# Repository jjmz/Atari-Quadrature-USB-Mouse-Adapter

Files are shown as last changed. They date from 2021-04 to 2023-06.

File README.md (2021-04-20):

# Atari-Quadrature-USB-Mouse-Adapter

New branch : uses platformio instead of ch554_sdcc. (Some init code from ch554_sdcc)

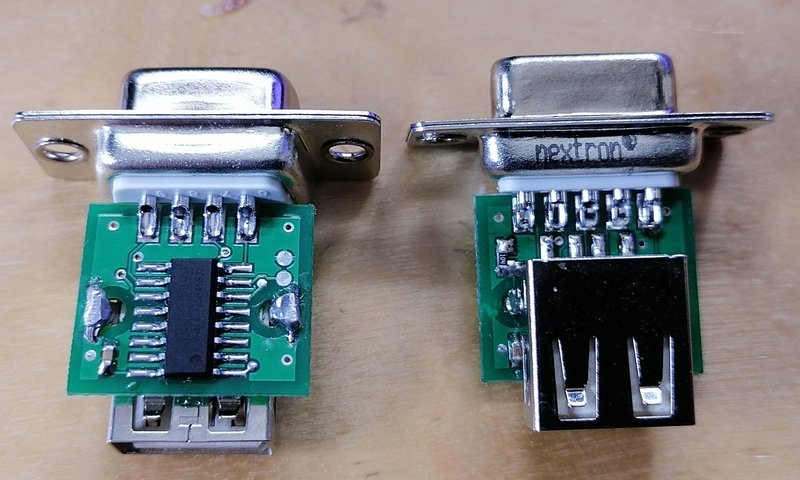
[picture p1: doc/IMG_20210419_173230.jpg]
Proto Photo


More info here : https://blog.pommerie-michel.fr/from-prototype-to-final-version-smallymouse-like-adapter-with-ch554/

Useful Tools :

- https://eleccelerator.com/usbdescreqparser/
- PyWinUsb - (examples/raw_data.py to check raw HID joystick output)
- SmallyMouse2 code source, for inspiration
-

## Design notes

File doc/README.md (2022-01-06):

# Doc

[Photo Gallery](https://github.com/jjmz/Atari-Quadrature-USB-Mouse-Adapter/blob/v2-platformio/doc/gallery.md)

[Reflash adapter - Linux](https://github.com/jjmz/Atari-Quadrature-USB-Mouse-Adapter/blob/v2-platformio/doc/ISP-Prog2.md)

[Reflash adapter - Windows](https://github.com/jjmz/Atari-Quadrature-USB-Mouse-Adapter/blob/v2-platformio/doc/ISP-Prog.md)

** Status LED

- LED OFF :
	Problem : CH554 not programmed, or in boot mode ?
	
	Boot mode is entered if the ISP pins are shorted
	
	It can be either P3.6 to VCC , or P1.5 to GND
	
	Note that P3.6 to VCC can happen if a full-speed device is connected to USB, thus the default on this project should really be P1.5. Please check that you are using this setting in the Windows WCH Flashing tool.

- LED ON, still :
	Program running, no recognized device on USB

- LED Blinking regularly :
	Mouse detected - mouse mode

- LED Pulsing : 1 pulse
	Joystick detected - default config (i.e. no specific config found)

- LED Pulsing : 2 pulses
	Joystick detected - using an entry in the joystick table

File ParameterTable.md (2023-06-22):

**WAS** DataFlash Offset:
**NOW** Memory Base : 0x3700 (i.e. 256 bytes before end of file)

    #0 (x02) - mouse DPI divider / TODO : bit 7 for Atari/Amiga switch
    #1 (x03) - step multiplier
    #2 (x08) - minimal increment
    #3 (x20) - maximal increment
    #4 -> #15 - to be used for buttons

    #16 - start of joystick table
        - one joystick entry => 20 bytes

Joystick Table

    #0-1 (0x0000) - Vendor ID (0 for default entry ,i.e. first one , 0xFFFF for unused)
    #2-3 (0x0000) - Product ID (0 for default entry, i.e first one)

    #4-5   (0x11-0x40) condition/value for Up
    #6-7   (0x21-0xC0) condition/value for Down
    #8-9   (0x10-0x40) condition/value for Left
    #10-11 (0x20-0xC0) condition/value for Right
    #12-13 (0x33-0xFF) condition/value for Fire Button 1 (multiple joystick buttons can trigger Fire)
    #14-15 (0xFF-0xFF) condition/value for Fire Button 2 (multiple joystick buttons can trigger Fire)
    #16-17 (0xFF-0xFF) condition/value for Fire Button 3 (multiple joystick buttons can trigger Fire)
    #18-19 (0xFF-0xFF) not used

Conditions encoding :

    0x0A-0xBB -> value at index A equals to BB
    0x1A-0xBB -> value at index A Lower than BB
    0x2A-0xBB -> value at index A Greater than BB
    0x3A-0xBB -> (value at index A and BB(mask)) is not zero
    0x4A-0xBB -> same as 0x1A (<) , but signed compare (ie 0x80 < 0x00 < 0x7F)
    0x5A-0xBB -> same as 0x2A (>) , but signed compare (ie 0x7F > 0x00 > 0x80)

Some examples :

- DragonRise - 0x0079 / 0x0006 - X,Y @ 0x01/0x00, buttons @ 0x06

    0x0F, 0x00,0x79,0x00,0x06, 0x11,0x40,0x21,0xC0, 0x10,0x40,0x20,0xC0, 0x36,0xFF,	

- 8bitdo / SN30 Pro - 0x2DC8 / 0x6001 - X,Y @ 0x04/0x03, buttons @ 0x00

    0x0F, 0x2D,0xC8,0x60,0x01, 0x14,0x40,0x24,0xC0, 0x13,0x40,0x23,0xC0, 0x30,0xFF,

- Logitech ATK3 - ???? ???? - X,Y @ 0x01/0x00, buttons @ 0x03

    cf Default Config

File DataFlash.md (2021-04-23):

DataFlash Offset:

    #0 (x02) - mouse DPI divider / TODO : bit 7 for Atari/Amiga switch
    #1 (x03) - step multiplier
    #2 (x08) - minimal increment
    #3 (x20) - maximal increment

    #4 - start of joystick table

Joystick Table

    #0 (0x0F) - offset to next table entry / 0xFF for last

    #1-2 (0x0000) - Vendor ID (0 for default entry)
    #3-4 (0x0000) - Product ID (0 for default entry)

    #5-6 (0x11-0x40) condition/value for Up
    #7-8 (0x21-0xC0) condition/value for Down
    #9-A (0x10-0x40) condition/value for Left
    #B-C (0x20-0xC0) condition/value for Right
    #D-E (0x33-0xFF) condition/value for Fire Button 1 (multiple joystick buttons will trigger Fire)

Conditions encoding :

    0x0A-0xBB -> value at index A equals to BB
    0x1A-0xBB -> value at index A Lower than BB
    0x2A-0xBB -> value at index A Greater than BB
    0x3A-0xBB -> (value at index A and BB(mask)) is not zero
    0x4A-0xBB -> same as 0x1A (<) , but signed compare (ie 0x80 < 0x00 < 0x7F)
    0x5A-0xBB -> same as 0x2A (>) , but signed compare (ie 0x7F > 0x00 > 0x80)

Some examples :

- DragonRise - 0x0076 / 0x0006 - X,Y @ 0x01/0x00, buttons @ 0x06

    0x0F, 0x00,0x79,0x00,0x06, 0x11,0x40,0x21,0xC0, 0x10,0x40,0x20,0xC0, 0x36,0xFF,	

- 8bitdo / SN30 Pro - 0x2DC8 / 0x6001 - X,Y @ 0x04/0x03, buttons @ 0x00

    0x0F, 0x2D,0xC8,0x60,0x01, 0x14,0x40,0x24,0xC0, 0x13,0x40,0x23,0xC0, 0x30,0xFF,

- Logitech ATK3 - ???? ???? - X,Y @ 0x01/0x00, buttons @ 0x03

    cf Default Config

DataFlash can be programmed independantly from the firmware code using the WCHISPTOOL.EXE
(Have not found a Linux program to modify DataFlash area)

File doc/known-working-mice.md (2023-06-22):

# Mice support

Tested (personally) :

| Name | USB IDs | Name (Linux) |
| --- | --- | --- |
| Cherry MC1000 | 046a:b091 | Cherry GmbH |
| Dell (M-UR69 ?) | 046d:c00c | Logitech, Inc. Optical Wheel Mouse |
| Dell (MS111-L ?) | 046d:c05a  | Logitech, Inc. M90/M100 Optical Mouse |
| Logitech B100 | 046d:c077 | Logitech, Inc,. M105 Optical Mouse |
| Logitech M185 | 046d:c542 | Logitech, Inc. Wireless Receiver |
| Dell (M-UAR DEL7 ?) | 413c:3012 | Dell Computer Corp. Optical Wheel Mouse |
| HAMA AMW-300 | xxxx:xxxx | HAMA wireless ("Action") |
| ACER AMR 9200 | 3938:1197 | Wireless (From Combo pack) |

Reported OK too by users :

| Name | USB IDs | Name (Linux) | Reporter |
| --- | --- | --- | --- |
| Microsoft sidewinder laser | | | |
| Logitech M720 (Dongle / BT mouse) | | | |
| Wireless (dongle) Logitech T620 touch mouse | | | |
| Logitech RX300 | | | |
| Genius GM-050014 U/A  Traveller 100 | | | |
| Seitek Cable Mouse, Model: PM34Azb | | | AndYManOne |
| Amazon, Model: Smartfox (Wireless) | | | AndYManOne |
| NoName Mouse, Model 1886 (Wireless) | | | AndYManOne |
| Red4Power, Model: R4-M010B (Wireless) | | | AndYManOne |
| Perrixx Mouse, Model: Perimice-711 (Wireless) | | | AndYManOne |
| Logitech Mouse, Model: M705 (Wireless) | | | AndYManOne |
| Logitech Zone Touch Mouse, Model T400 (Wireless) | | | AndYManOne |
| NN Mouse (No Model) The very flat version (Wireless) | | | AndYManOne |
| Sunflower Cable Mini Optical Mouse, Model: SF-2035 | | | AndYManOne |
| Logitech Cable Mouse, Model: RX 250 | | | AndYManOne |
| A500 Mini - original USB Amiga-Style Cable Mouse | | | AndYManOne |

Not Working

| Name | Remark |
| --- | --- |
| HAMA AMW-150 (wireless) | Not supported in Dell BIOS |
| Speedlink, Model: AXON SL6302-GY (Wireless) | |
| Microsoft Mouse, Model: 1850 (Wireless)  | |

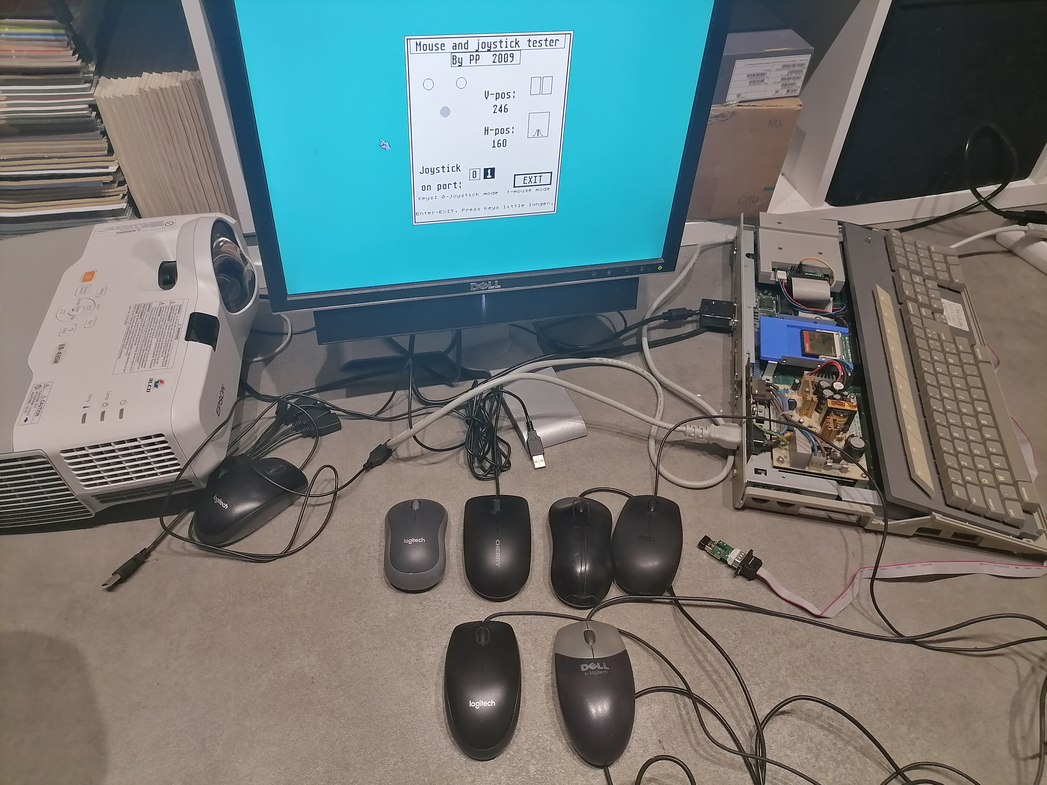
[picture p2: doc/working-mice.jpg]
working-mice


# Joysticks

From the joystick table (.h file)

| "Name" | USB IDS | Pic1 | Pic2 |
| --- | --- | --- | --- |
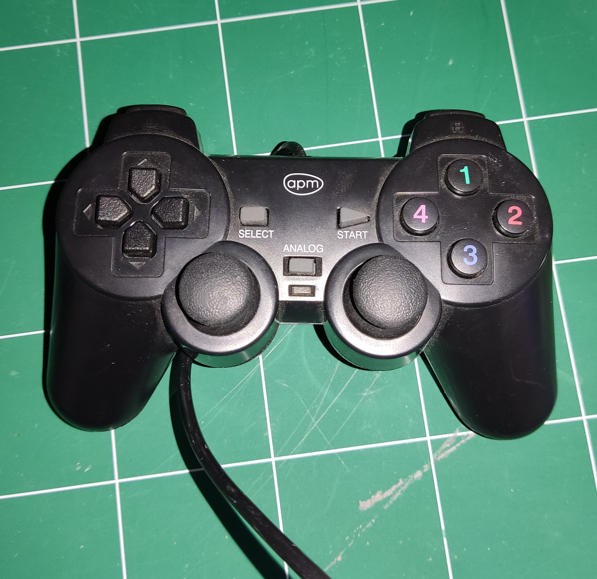
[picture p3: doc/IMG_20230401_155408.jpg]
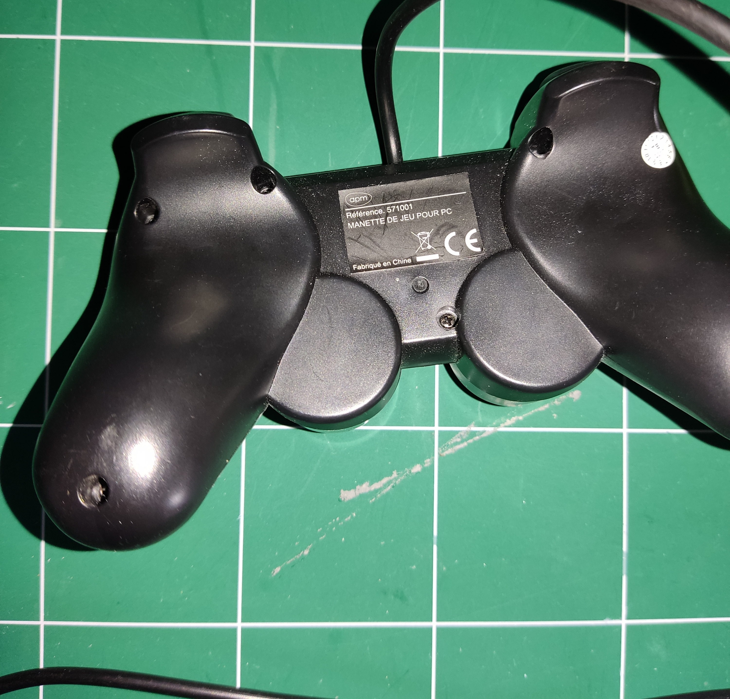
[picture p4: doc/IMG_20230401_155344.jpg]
| TWINSHOCK (Also DragonRise Inc. Generic USB Joystick) |	0079-0006 |  |  |
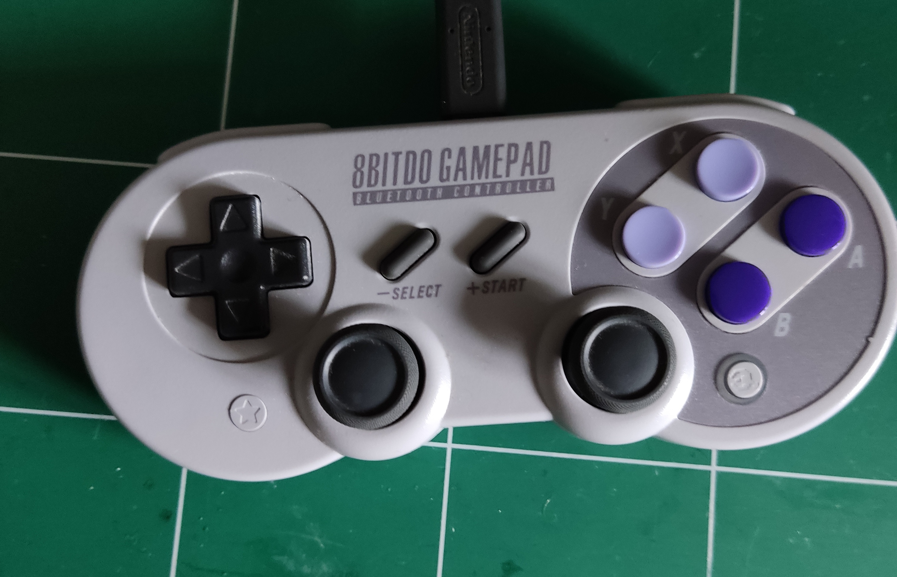
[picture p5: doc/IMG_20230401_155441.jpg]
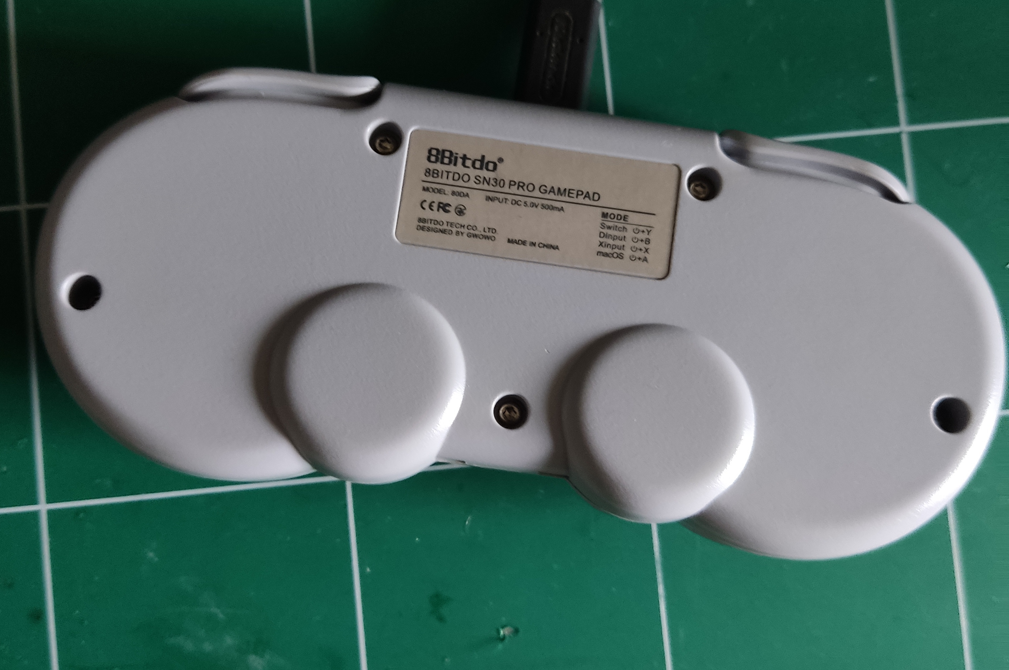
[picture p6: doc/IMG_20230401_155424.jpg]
| EIGHTBITDO_SN30 (Dinput mode) | 2DC8-6001	|  |  |
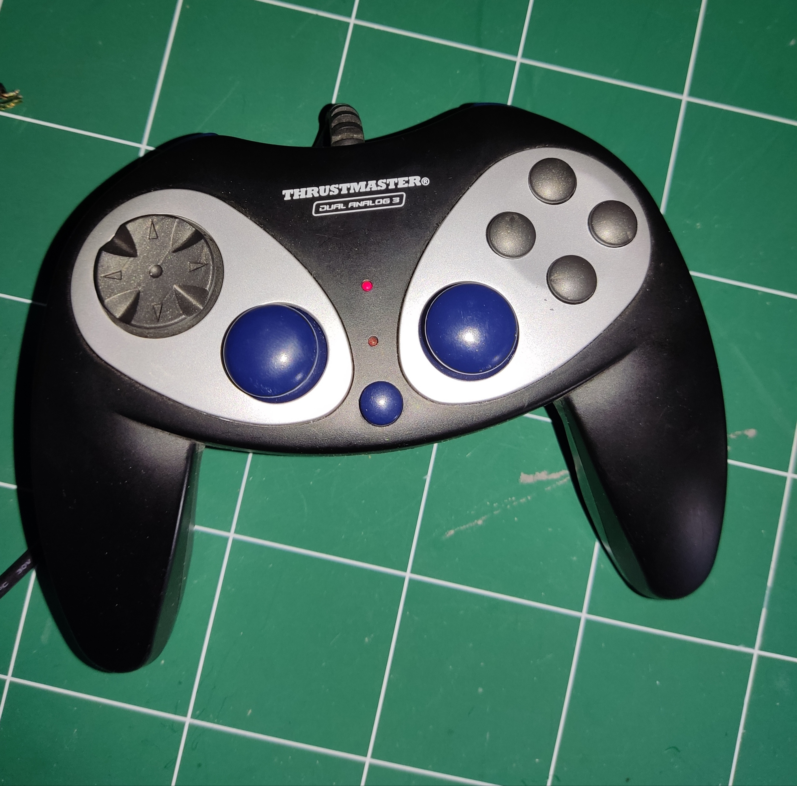
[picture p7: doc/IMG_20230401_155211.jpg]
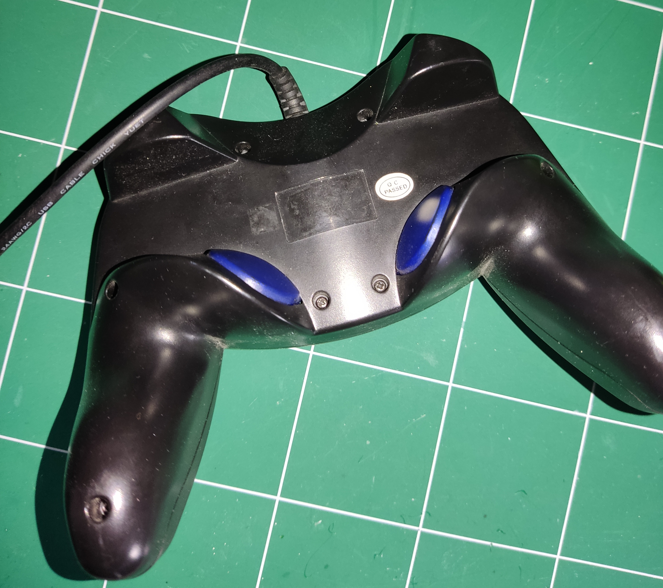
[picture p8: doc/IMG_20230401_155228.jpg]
| THRUSTMASTER | 044F-B315 |  |  |
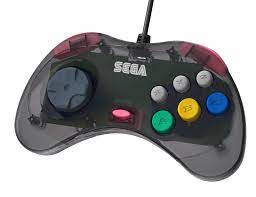
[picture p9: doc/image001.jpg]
| PAD | 0079-0011 |  | |
| GP1 | 0810-E501 | | |
| GP3 | 0810-0003 | | |
| HAMA | 12BD-A02F | | |
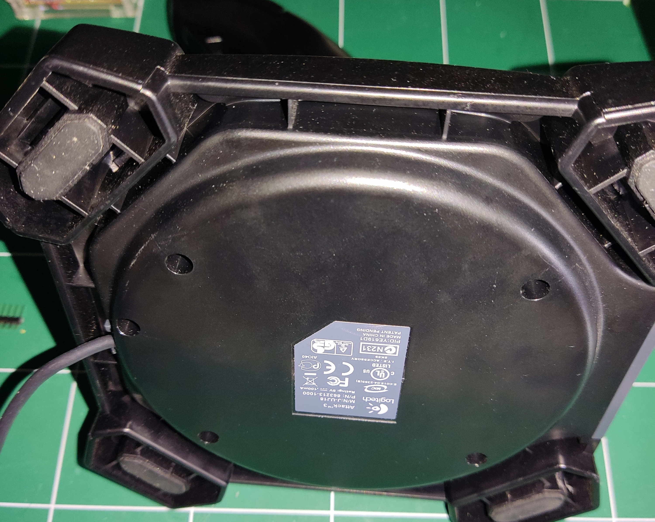
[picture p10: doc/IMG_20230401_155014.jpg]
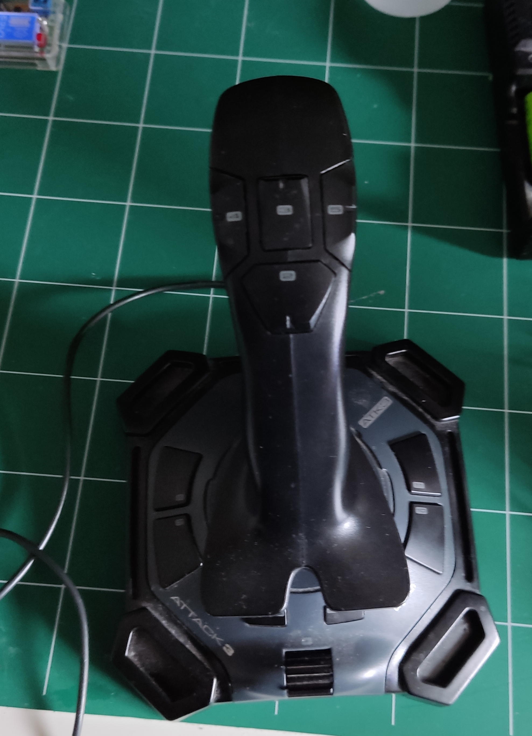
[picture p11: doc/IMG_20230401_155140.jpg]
| LOGITECH_ATK3 | 046D-C214 |  |  |
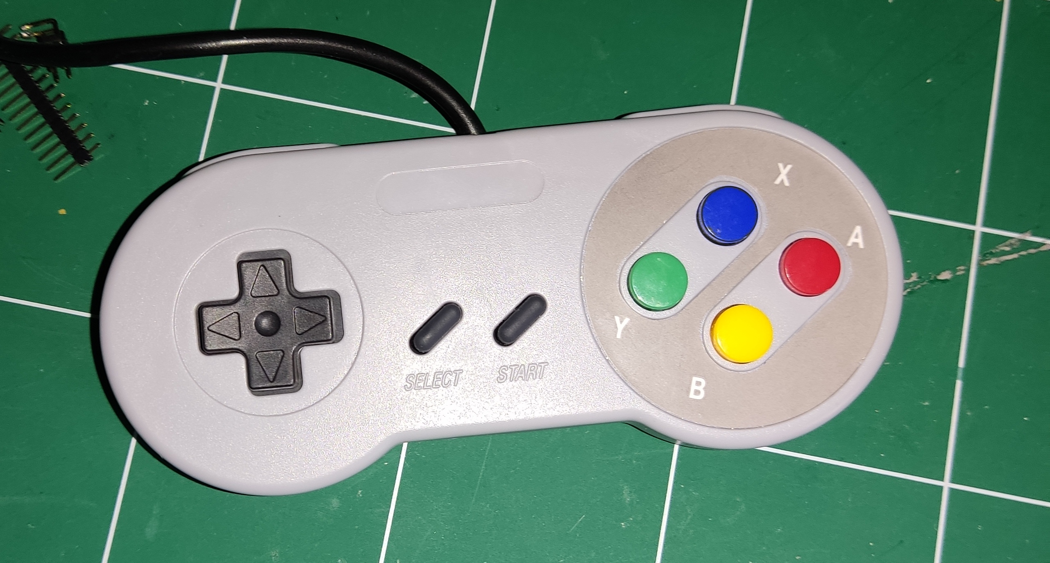
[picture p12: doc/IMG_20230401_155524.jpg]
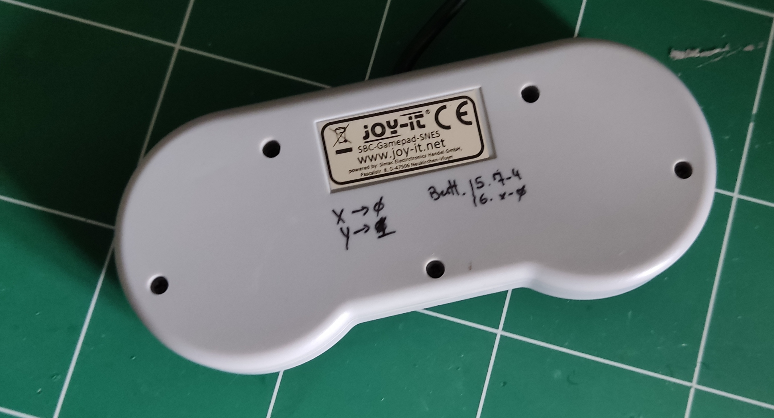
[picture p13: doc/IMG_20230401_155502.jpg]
| By Default (for example USBID) | xxxx-xxxx (081f-e401) |  |  |

Best Value : https://www.gotronic.fr/art-manette-pour-superpi-usb-gamepad-29672.htm

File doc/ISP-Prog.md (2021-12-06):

## CH55x Bootloader

I think you can have 3 cases when powering the CH55x :

1. Unprogrammed CH55x

   When the CH55x is unprogrammed, it will by default go in bootloader mode, with no specific pin to short.

2. Factory default (after 1st flashing, if nothing is done regarding download cfg), or if P3.6 was selected

   To go in bootloader mode, then a __temporary__ connection of P3.6 with VCC is needed while powering the chip.
   This __SHOULD NOT__ be the default for this project, as connecting a full-speed device to the USB would cause the CH55x to enter bootloader mode too (Full-speed devices have a pull-up connected to D+).
   On the USB adapter, VCC and P3.6 are accessible on two test pads, near the USB connector (check the photos with the tweezers)

3. Alternative download cfg : via P1.5 - info found here[^1]

   This is the configuration I am using - note that P1.5 has to be connected to GND - both pins are present on the DB-9 connector : P1.5 is pin 2 , GND is pin 8.
   You can use a short wire, or even a paper clip to connect those 2 pins, and can even leave it after powering the adapter, while reflashing.

## Windows WCH utility

Software to use : WCHISPTOOL ([local copy here](WCHISPTool_Setup.exe?fileId=854562))

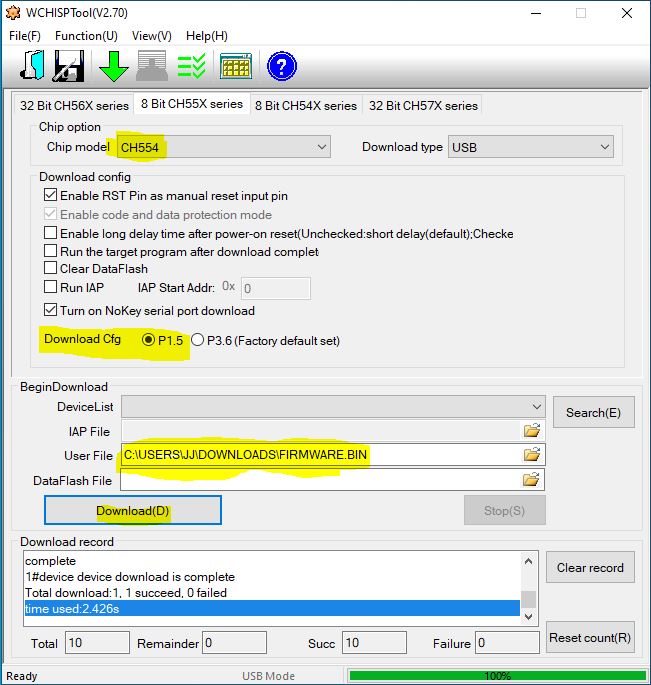
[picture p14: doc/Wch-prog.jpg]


Need to use a Male-Male USB cable (or adapter) :

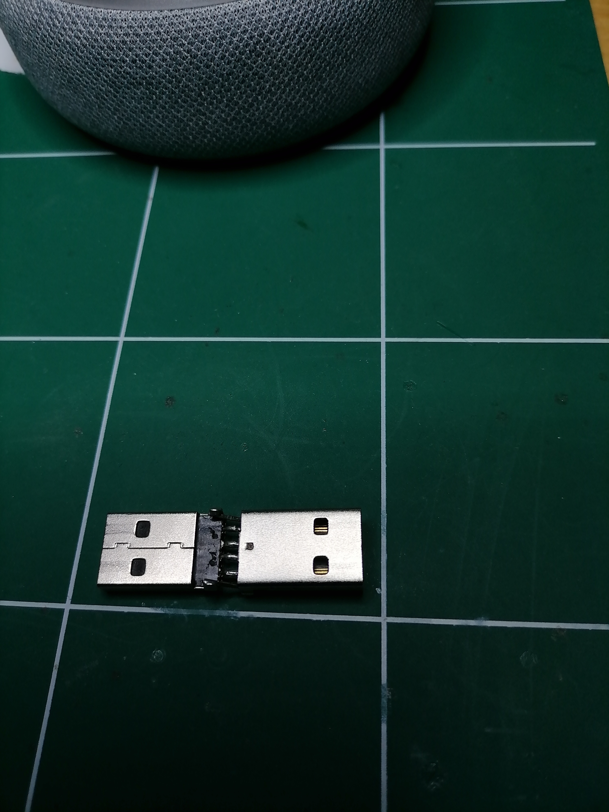
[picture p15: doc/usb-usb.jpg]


V1-Bootloader-Pins :



V2-Bootloader-Pins (only the two test pins - forget about the white wire) - same a V1, but smaller :

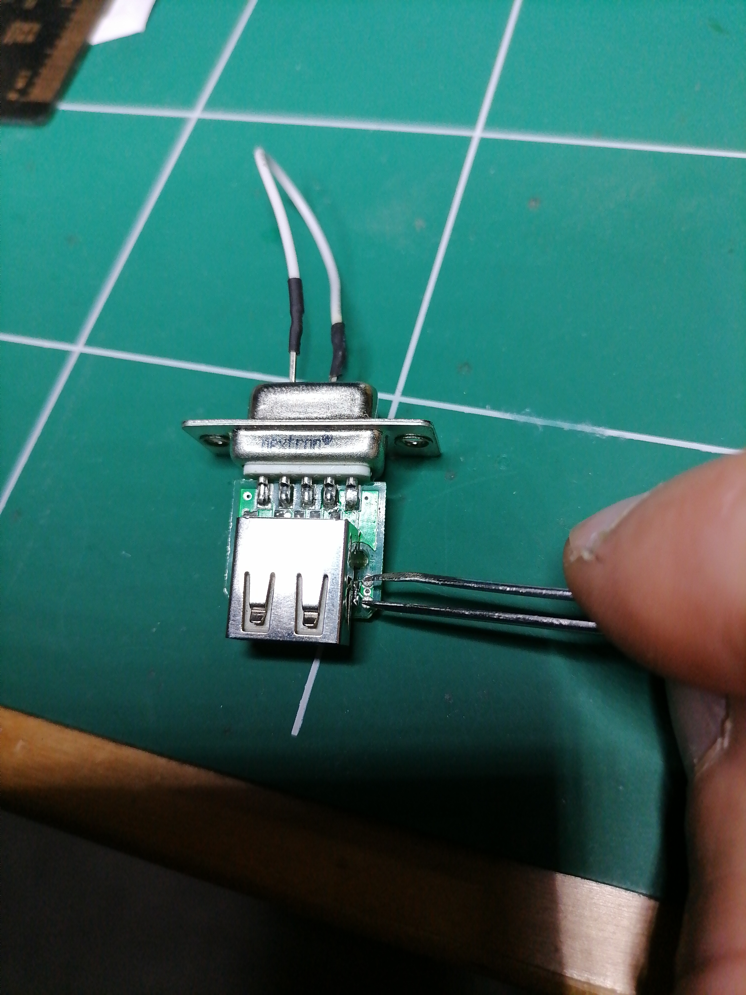
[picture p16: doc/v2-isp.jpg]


V2-Alternate-Bootloader-Pins (DB9-2 (P1.5) and DB9-8 (Gnd)) :

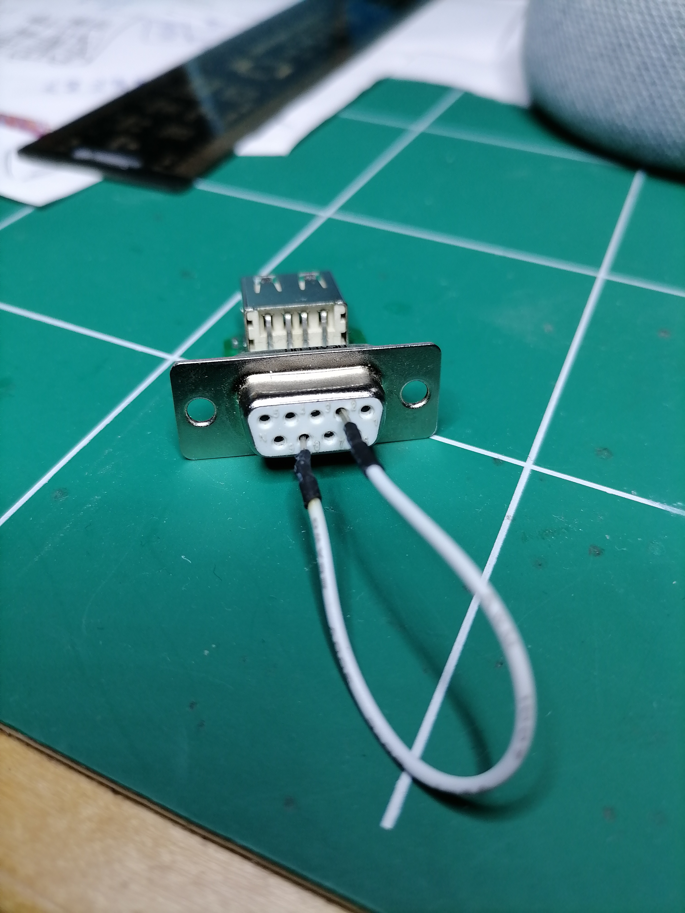
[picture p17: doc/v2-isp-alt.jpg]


Some Misc photos :

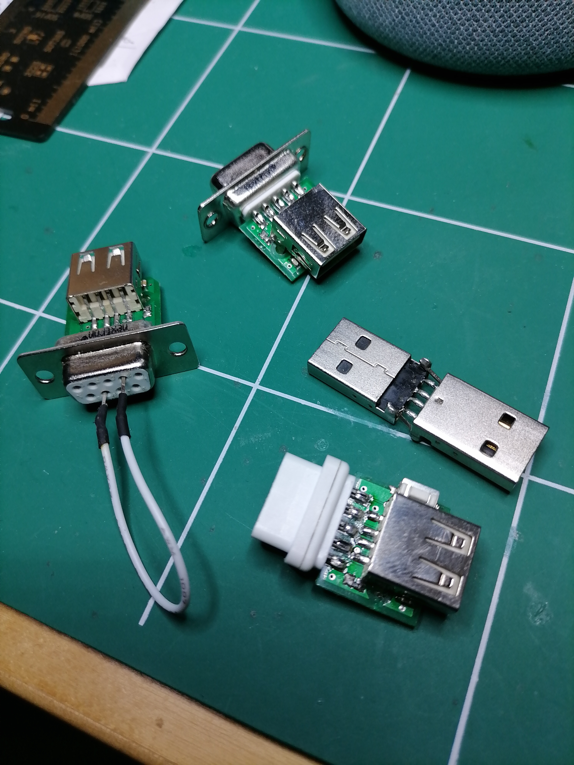
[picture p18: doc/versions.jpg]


References :

[^1]: http://rabid-inventor.blogspot.com/2020/05/getting-started-with-ch55x.html

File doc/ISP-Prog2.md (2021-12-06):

## Reflashing the adapter

1. Connect Pin 2 (P1.5) with Pin 8 (Gnd) on DB-9

-> See picture (v2-isp-alt.jpg)
v2-isp-alt

(If 'download cfg' was not P1.5, then the pins to short are the test pins on the PCB.)
See [v2-isp](v2-isp.jpg) 
See also more info on the Windows ISP-Prog page : [here](ISP-Prog.md)

2. Connect USB to USB on a computer (you need a USB Male-to-Male cable, or an adapter)

Linux detects CH554 in boot mode as idVendor=4348, idProduct=55e0

(dmesg output example)

```
[603279.266447] usb 3-9: new full-speed USB device number 7 using xhci_hcd
[603279.415593] usb 3-9: New USB device found, idVendor=4348, idProduct=55e0, bcdDevice= 2.40
[603279.415596] usb 3-9: New USB device strings: Mfr=0, Product=0, SerialNumber=0
```

3. Use "python3 ch55xtool.py -f firmware.bin"

(ch55xtool.py included in repository - needs python usb lib)

Output :

```
jjm@local:~$ python3 ch55xtool.py -f firmware.bin 
Found CH554.
BTVER: V2.40.
Flash done.
```

Or use the Windows 'wchisptool' [ISP-Prog](ISP-Prog.md)

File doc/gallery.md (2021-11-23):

Some photos/pics/snapshots :

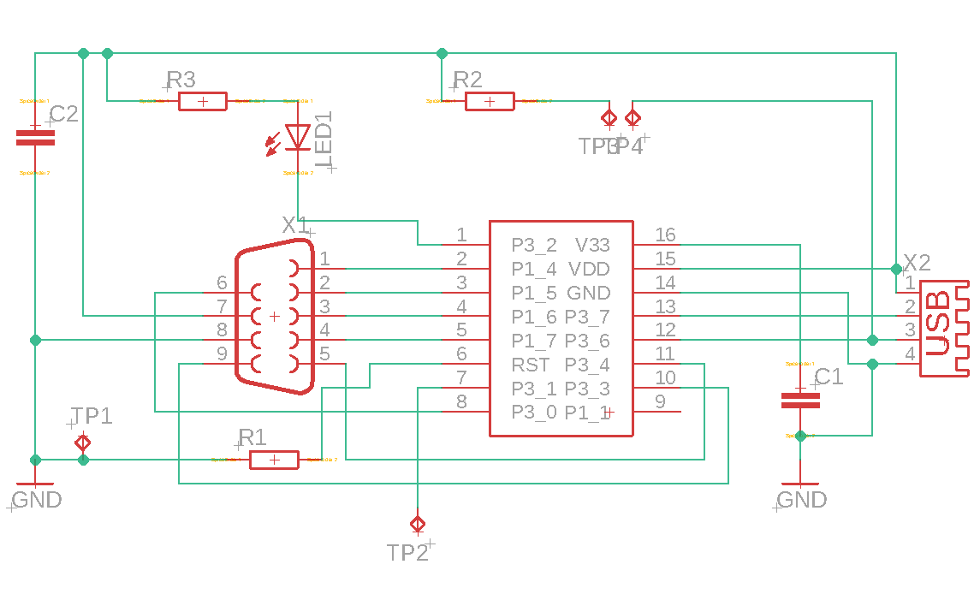
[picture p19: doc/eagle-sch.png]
Schematic

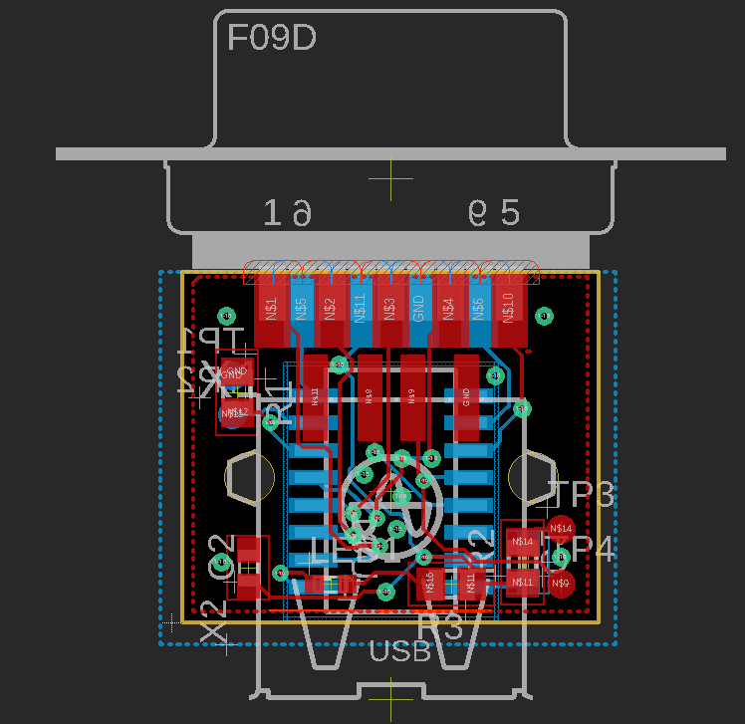
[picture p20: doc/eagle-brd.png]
Board


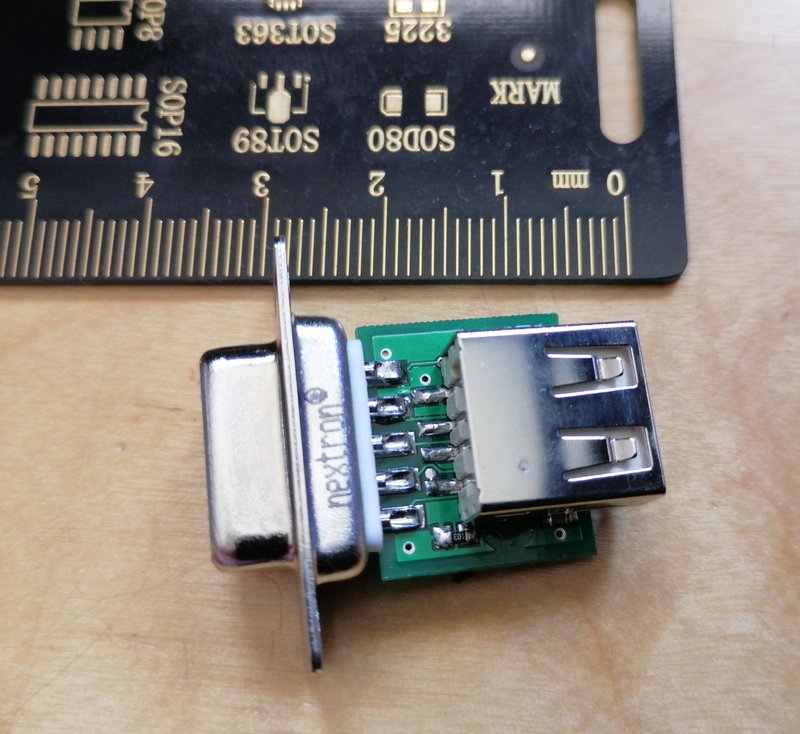
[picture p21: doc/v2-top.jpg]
v2-top

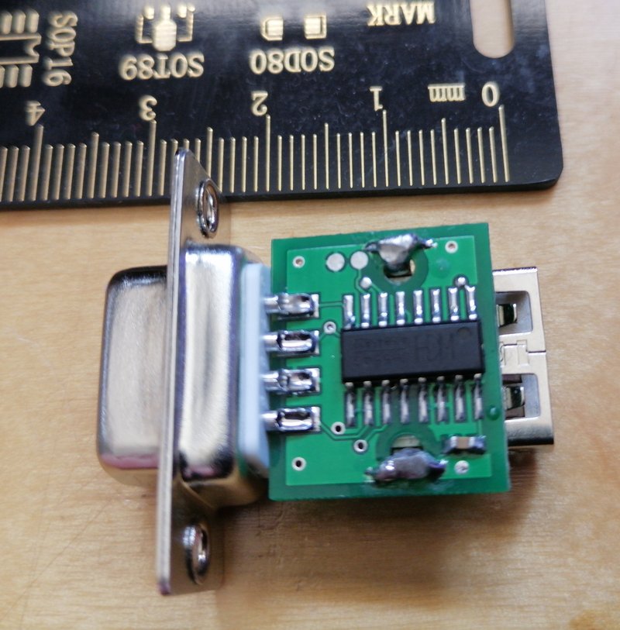
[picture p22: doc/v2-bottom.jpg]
v2-bottom

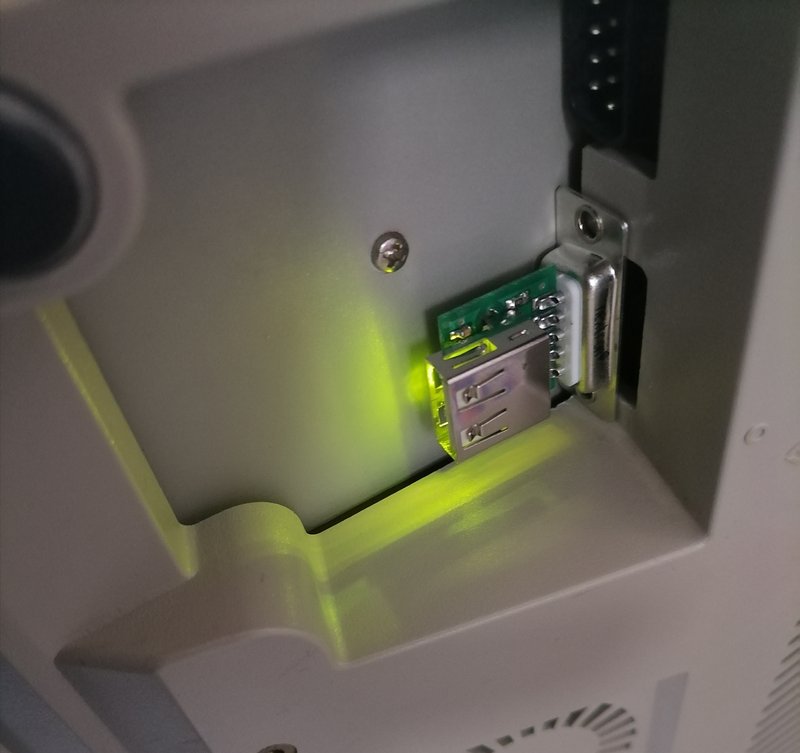
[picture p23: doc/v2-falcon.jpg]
v2-falcon1

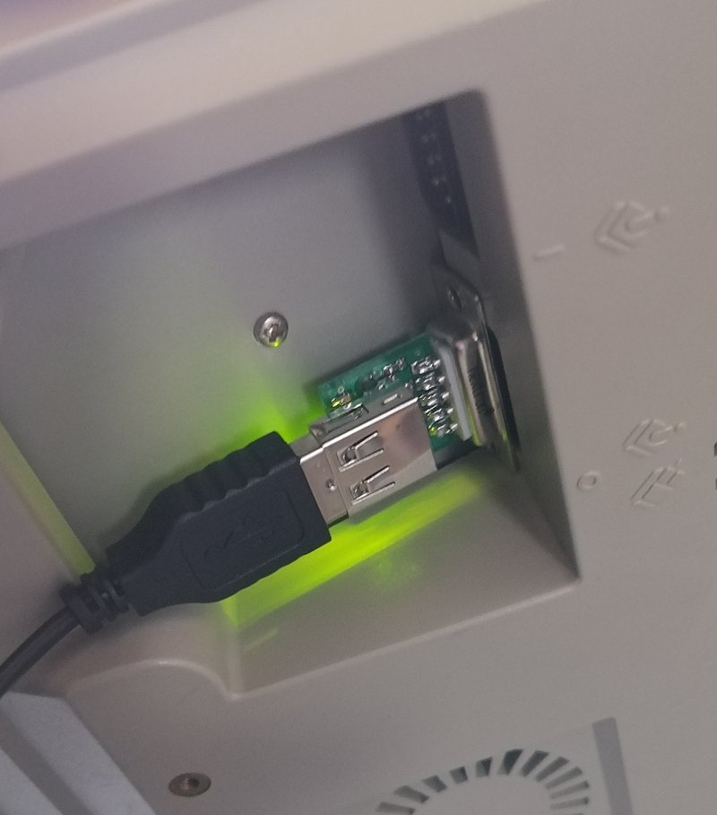
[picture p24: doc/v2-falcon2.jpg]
v2-falcon2


working-mice

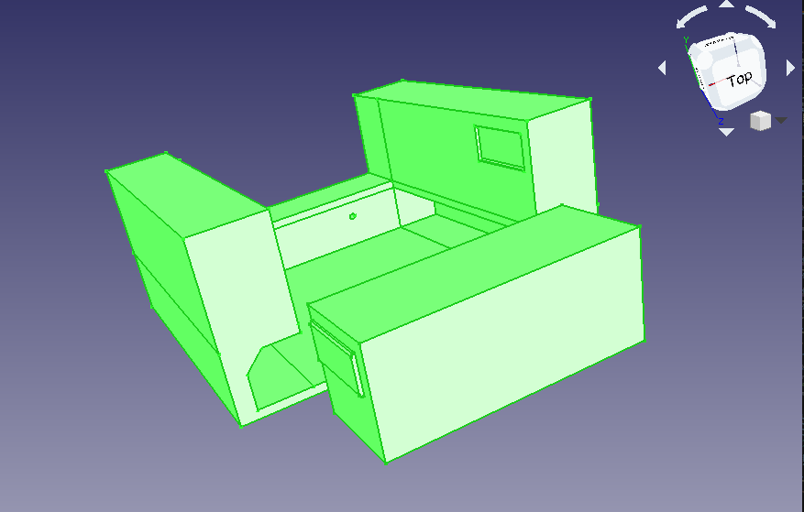
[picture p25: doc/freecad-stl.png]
STL


v2-case1
v2-case2

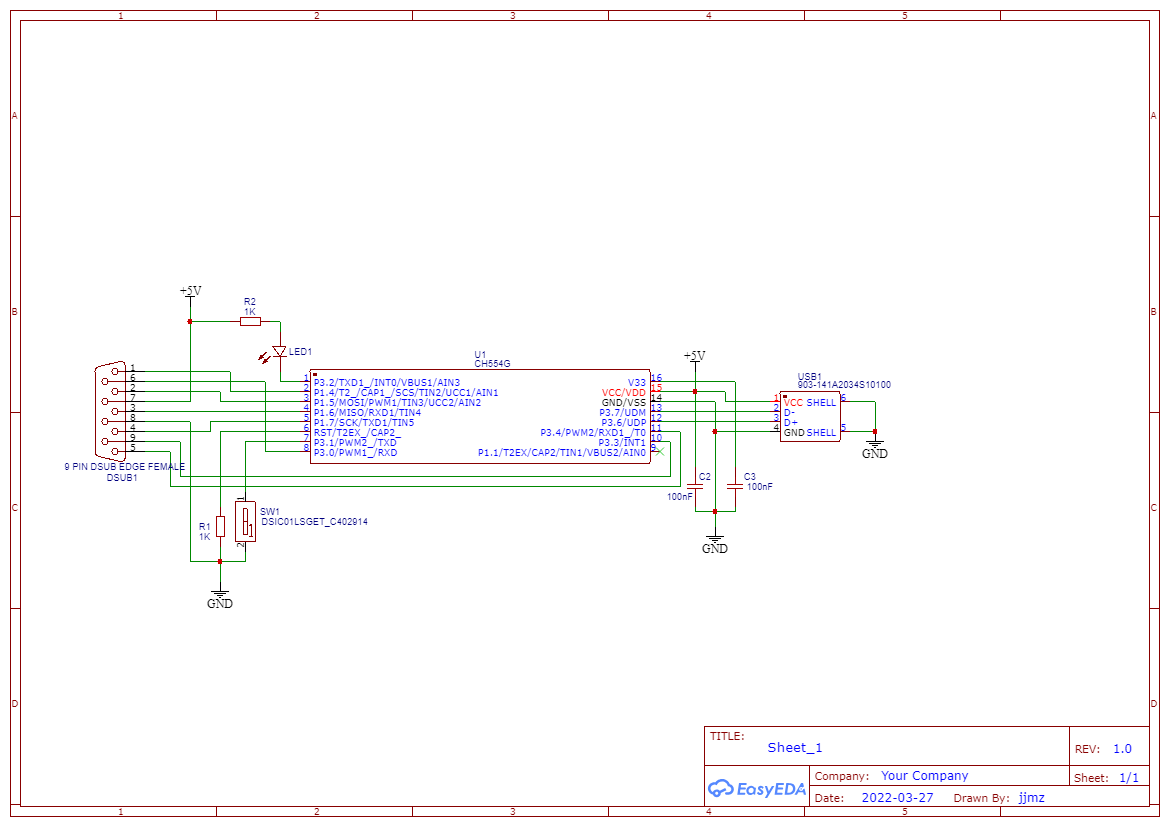
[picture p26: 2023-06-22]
doc/gerbers/Schematic_Nomquad_2023-06-19.png

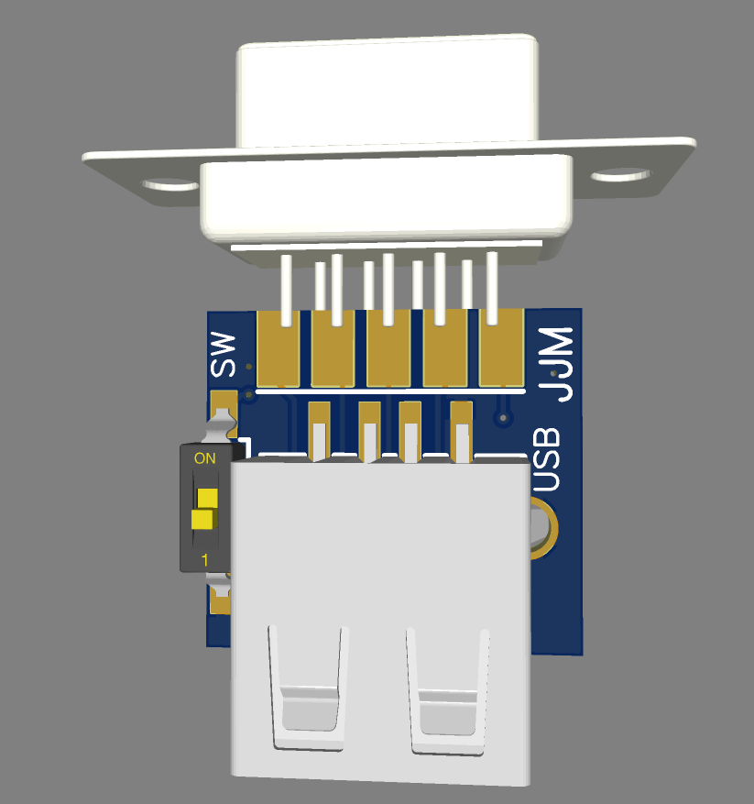
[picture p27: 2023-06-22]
doc/gerbers/2023-06-19 16_36_47-EasyEDA(Standard) 6.5.22 - Team Work mode.png

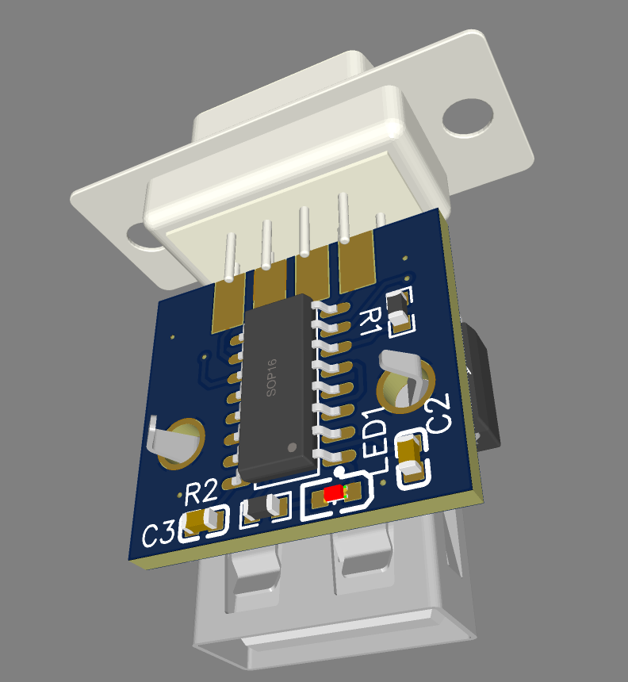
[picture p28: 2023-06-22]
doc/gerbers/2023-06-19 16_36_19-EasyEDA(Standard) 6.5.22 - Team Work mode.png

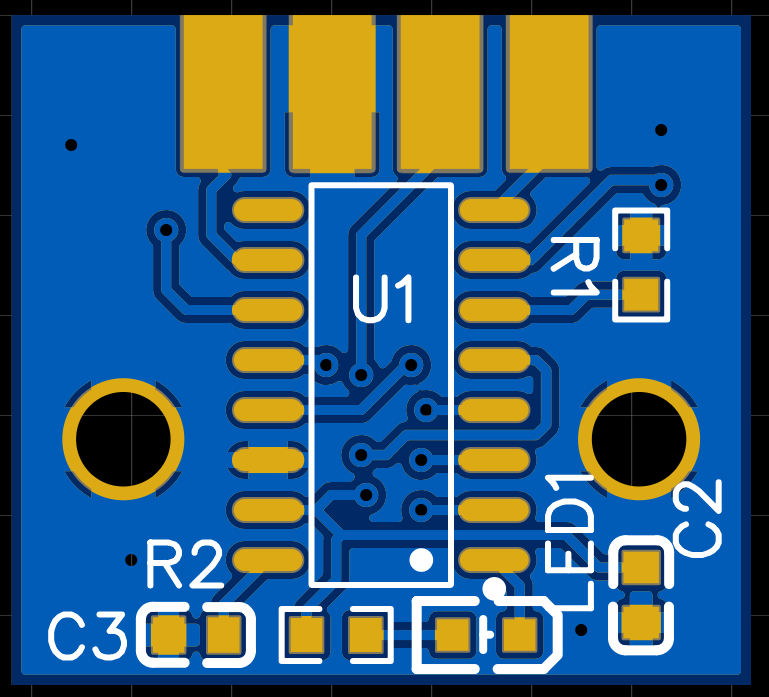
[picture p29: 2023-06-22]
doc/gerbers/2023-06-19 16_35_23-EasyEDA(Standard) 6.5.22 - Team Work mode.png

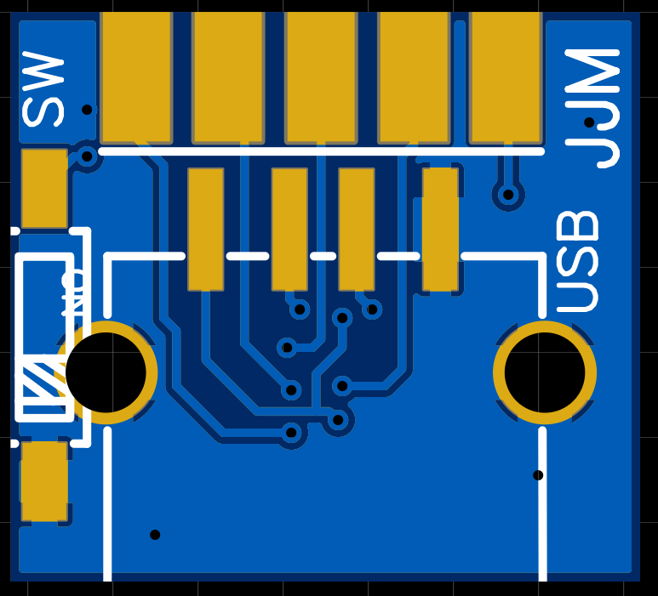
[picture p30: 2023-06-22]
doc/gerbers/2023-06-19 16_34_47-EasyEDA(Standard) 6.5.22 - Team Work mode.png

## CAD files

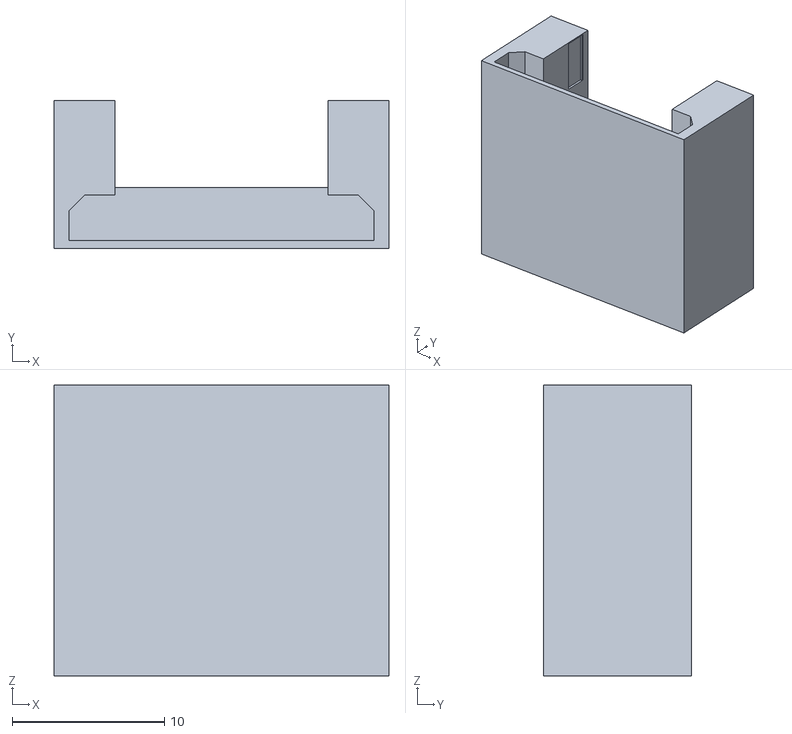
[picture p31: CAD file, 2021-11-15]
doc/nomquad.stl
22.0 x 9.70 x 19.1

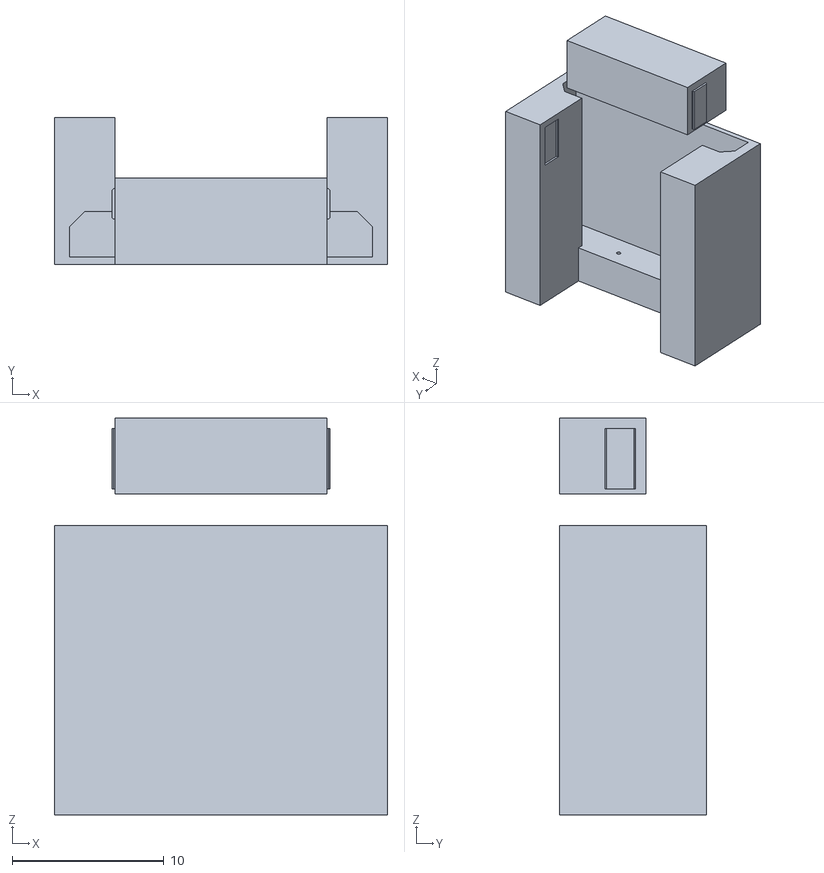
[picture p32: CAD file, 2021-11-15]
doc/nomquad-all.stl
22.0 x 9.70 x 26.2

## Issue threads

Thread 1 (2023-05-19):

How to switch between Atari and Amiga

mamejay, 2023-05-19:
Hello there. I just discovered this project.  I see that you mention Amiga and Atari but how do you switch between the two?
On the schematic in the DOCS folder I can see a TP2 which I suspect you may need to pull high or low.
Can you confirm what needs to be done?  I will to make one of these and have it support both systems..

Thanks

jjmz, 2023-06-10:
True, I habe been using tp2 as serial output for debug in the beginning, but now ground it to use amiga mode. Sorry for late answer....

mamejay, 2023-06-11:
thank you!!

Closed 2023-06-16.

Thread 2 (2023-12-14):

Testing Rig

mamejay, 2023-12-14:
Hello there.  I noticed on your blog you have a testing rig setup with LED's.
Do you have any information about this and how to build it?  I suspect it would work on a Arduino or other micro controller.
Thanks

jjmz, 2023-12-14:
Hi,
The testing rig is really only 7 LEDs with 330 ohm resistors in serie.
The DB9 has GND/VCC + 7 I/Os (Up/Down/Left/Right - 3 buttons Left-Middle-Right).
It just allows me to check if all connections are OK, and that X/Y pulses are ok.
JJ

neo-rg, 2024-02-09:
Found the project very interesting, is there a way to adjust the polling and limit high dpi mice. lowering the dpi and making the mouse less twitchy?

jjmz, 2024-02-10:
Hello, in the code (or firmware), the table at 0x3700 contains : divider (1 byte) then multiplier (1 byte) (the table for Amiga is 8 bytes further at 0x3708, and first byte must have 0x80 added). You can try to increase divider to reduce dpi resolution.

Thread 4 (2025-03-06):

Problems with Joypad

oO-cozy-Oo, 2025-03-06:
Thank you for this amazing project,got my Amiga mouse working great,but I`m having trouble with cheap joypad (IMG_20230401_155524.jpg)
not working it seams that the fire button is pressed but its not? I`ve got two and other generic pads still the same.The LED is pulsing
Im using the latest .bin file.
Thanks again
Rich

jjmz, 2025-03-10:
Rich,
If you have a look at the code, you will notice that only 8 joysticks are supported (the ones with non-null VID/PID) :

#define DEFAULT_JOYSTICK                0x00,0x00,0x00,0x00,	\
// VID-PID : 0079-0006
#define TWINSHOCK				        0x79,0x79,0x06,0x06,	\
// VID-PID : 2DC8-6001
#define EIGHTBITDO_SN30			        0xC8,0x2D,0x01,0x60,	\
// VID-PID : 044F-B315
#define THRUSTMASTER			        0x4F,0x04,0x15,0xB3,	\
// "Saturn Retrobit" - A+B on Button1 35 60 , C on Button 2 -> 36,01 / John prefers 35 A0
#define PADCEDRIC						0x79,0x00,0x11,0x00,	\
// VID-PID : 0810-E501
#define JOHN_GP1				        0x10,0x08,0x01,0xE5,	\
// VID-PID : 0810-0003
#define JOHN_GP3				        0x10,0x08,0x03,0x00,	\
// VID-PID : 12BD-A02F
#define JOHN_HAMA				        0xBD,0x12,0x2F,0xA0,	\
// idVendor 0x046D // idProduct 0xC214
#define LOGITECH_ATK3					0x6D, 0x04,  0x14, 0xC2,  \

If the joystick you connect is not in the table, a 'default' config is used - the adapter v1 does not parse the HID descriptor table to try to do better detection.
If you provide PID/VID and the HID table, I could give you some values to put in the joystick table to try to support your joysticks, but consider that v1 is no more supported, and I won't try to implement better HID parsing, as I am working on a v2 that has a different uC and that should be more 'configurable' /  user friendly.

JJ

PS: there are some Python code in the repository to get HID descriptors (I don't remember how they are working) - I think I also used usbhid-dump under Linux to get descriptors.

oO-cozy-Oo, 2025-03-10:
Thanks for the reply JJ i`ll try and have a play as in a windows guy and not really used to python scrips,

thanks again
Rich

ps great project thanks nice little usb adapter!!!!

oO-cozy-Oo, 2025-03-15:
Hi JJ,
Been trying my best with the python scrips, so here gos

VID=0x07d5 PID 0x0215

raw_data.py It gave me these readings for each press on the joypad

but Im unable to convert this to the orther reading like "0x14,0x40,0x24,0xC0,"????

[url=https://ibb.co/BHDzwZw5][img]https://i.ibb.co/wZH0YWYF/Untitled.jpg[/img][/url]
[url=https://ibb.co/C3btGn6q][img]https://i.ibb.co/39psZ0vw/veder.jpg[/img][/url]

cheers

Rich (cozy)

jjmz, 2025-03-15:
Hello,

From your data, I think you could try to change the default entry :
DEFAULT_JOYSTICK                0x00,0x00,0x00,0x00,	\
								        0x11,0x40,0x21,0xC0,	\
										0x10,0x40,0x20,0xC0,	\
										0x35,0x50,0x35,0xA0,	\
										0xFF,0xFF,0xFF,0xFF
By
DEFAULT_JOYSTICK                0x00,0x00,0x00,0x00,	\
								        0x11,0x40,0x21,0xC0,	\
										0x10,0x40,0x20,0xC0,	\
										**0x32,0x03,0x32,0x0c**,	\
										0xFF,0xFF,0xFF,0xFF

Or put a dedicated entry at the end of the table with the VID=0x07d5 PID 0x0215
                0xD5,0x07,0x15,0x02,	\
								        0x11,0x40,0x21,0xC0,	\
										0x10,0x40,0x20,0xC0,	\
										0x32,0x03,0x32,0x0C,	\
										0xFF,0xFF,0xFF,0xFF

The tables are at the end of the binary file, near offset 0x3800 if I remember correctly.
Sorry, the format is a bit obscur - I tried to explain my logic in a readme somewhere, but I doubt anybody can understand...
First bytes are of course the pid/vid in little endian. Then you have up/down left/right with comparaisons/index/threshold : hex '1x' is for < compare , 'x' is the byte index, and 40 is the threshold, so 1140 is compare byte 1 with 0x40 and thus up is active if byte 1 is lower than 0x40.
21c0 is compare byte 1 with 0xc0 and down will be active if byte 1 is higher than 0xc0
Same for left/right but with byte index 0 [note that in your python output, I think that the first 0 should be discarded ]
The 0x3. serie is for button 1 and 2. 0x3 is for mask comparison : 0x32 03 means 'and' byte 2 with mask 3 and action if non null. In your case, it would be active for button 1&2, 0x32 0c would be active for button 3&4.

By the way, my v2 is almost finished - would you want to beta test it? PM me at jjmz@free.fr and I would be glad to send you a pre-version if you help me debug it (especially on amiga, as I have no experience on them)

oO-cozy-Oo, 2025-03-15:
Thank you JJ for the fast reply and to explain , But my other problem is to make the new firmware.bin with the modified code.
I did look at the .bin file in mt HxD editor but was unable to fine the code to change it. I also looked at the source code and found the joystick-table.h which I could change it But Im at a loss at compliling code.
Sorry to be a pain is there any chance of a firmware.bin file with my settings in it.

Cheers Rich ( oO-cozy-Oo)

oO-cozy-Oo, 2025-03-15:
Also is there any where I can give a donation for the work you have done>

jjmz, 2025-03-15:
Preview of the config file for v2 . Do you think there is enough configurability (config is changed by inserting a USB flash) ?

`[Debug]
# Enable/Disable Debug TX on DB9-3 (ch32 uart 1 = PB10) - 115200 bps
TxViaDB9-3=0
# Reduce verbosity if USB data repeats
LogOnlyDelta=1
# Reduce verbosity if HID Parser is not needed
LogHIDParser=0

[Hardware]
# DB9 pin mode : o=open-drain, p=push-pull , order 1234/LMR
DB9Port   =oooo/ooo
# DB9 pin config for PS/2 output (not impl. yet)
AltDB9_PS2=..../...
# Max Quad signal frequency
QuadMaxFreq=2300

[Mouse]
# Use mouse boot protocol (force->no HID parsing)
ForceBootProto=0
# Mouse Mode : Atari/Amiga/PS2
Mode=Atari
# Mouse Button mapping (0..n), left to right
Rbutton=x..x...
Mbutton=..x....
Lbutton=.x..x..

[Joystick]
# Pad Mapping, usually <>^v
PadLRUD=<>^v<>^v........
# Hat Mapping, usually from 0 to 7, 0=up, then clockwiseHatLRUD=N,NE,E,SE,S,SW,W,NW
# Button mapping for Directions
ButLRUD=....<>^v
# Fire Button to USB button mapping (x=normal,!=autofire)
#       0123456789012345
Fire1  =.x........!.....
Fire2  =..x........!....
Fire3  =x..!............
# AutoFire Frequency
AutoFireFreq=5

[LED]
Idle       =002000
MouseBoot  =080008
MouseReport=200020
Joystick   =202000
MassStorage=201000
`

jjmz, 2025-03-15:
`
test
`

jjmz, 2025-03-15:
What do you think of the future configurability of v2 ? A preview of the config.txt , is here :

https://github.com/jjmz/Atari-Quadrature-USB-Mouse-Adapter/blob/v2-platformio/preview-config-v2.txt

oO-cozy-Oo, 2025-03-15:
wowww thats nice

oO-cozy-Oo, 2025-03-15:
Just reflashed and directions are spot on!! and two out of the four buttons are working as the fire , the other two are doing nothing..
Is it possable to make all four buttons work as the fire button.

cheers Rich

jjmz, 2025-03-16:
Cool.

Just change 32 03 by 32 0F, it should make all buttons active.

Le 15 mars 2025 21:06:15 GMT+01:00, oO-Cozy-Oo ***@***.***> a écrit :
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
--
Envoyé de mon appareil Android avec Courriel K-9 Mail. Veuillez excuser ma brièveté.

oO-cozy-Oo, 2025-03-16:
Thank you again JJ !!!!!

cheers
Rich

oO-cozy-Oo, 2025-03-20:
Hi JJ is this the right location to add a dedicated Joypad.

cheers Rich

"Or put a full table entry only for your joystick at 3774 such as :

D5 07 15 02 11 40 21 C0 10 40 20 C0 32 03 32 0C FF FF FF FF"

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

jjmz, 2025-03-21:
Rich,

Yes, I think that's the right place : each entry is 20 bytes long and starts at @3710, thus the @3774 (offset 0x64 = 100d = 5*20) would be the 6th entry in the table. From the beginning of the project the 4 last bytes in each entry are FF, as they are not used (planned for future use, but it never happened...). Also, don't forget to change the last 32 03 32 0C by 32 0F FF FF, since you wanted to have all 4 buttons to act as fire button 1.

oO-cozy-Oo, 2025-03-21:
Thank you JJ I did think that was right , just wanted to check before I
flashed the adapter.

Thanks again for your time to explain everything.

Cheers
Rich

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

Closed 2025-03-15.

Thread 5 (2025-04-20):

Not really an issue ^^

domBavay, 2025-04-20:
Bonjour, je vais tâcher d'écrire en anglais pour que tout le monde puisse lire :)
Hello :)
I introduce me, i am dominique and i played a lot with my atari st when i was young (in 1990, i was 11)  i found an old dead one on the internet, and repaired it (it was only the power supply) all my old disks are lost :(
 Thanks for this amazing job ! impressive reduction from first stm32 prototype to smallyMouse !

i bought ch554G (25) on ebay, and bought 10 boards from jlcPCB, i soldered one to test, but i do not have resistors values, seems that there is a 200 ohms and a 10 kohms but not sure about it, can you please tell me where to get this info or tell me about thoses resistors :)
 the ch554g is not regognized by windows (makes an error)  maybe beacause of lack of the two 100nF capacitors? (i will get some in next days) i only have 1206 ones, and no one at home, only at work. i will order 0603 ones

Second question, i am building it for an atari st, and i was wondering if i need to short cut the switch pad for the atari use, or for the amiga use?

Last point, just for story ^^ , i am working on a SD card reader from STM32 to simulate floppy disk and plug it on the IDE ribbon cable, with an lcd display to select disk and virtually insert them :)
i collected lot of docs from Jean Louis Guérin (DrCoolZic) 's site, for floppy and st docs.
Thanks a lot
regards,
dominique

jjmz, 2025-04-20:
Salut Dominique,

For the resistors value, I use 2x ~1k (I had a stock of 1k1). The one on reset is not really needed, the other one is for the led.
To be detected on Windows (with the Wch tool), I think that only the capacitor on 3v3 is really needed. The other one is decoupling on 5v.
On an atari, the dip switch is not needed. You need a short only for Amiga.

Good luck.

jjmz, 2025-04-20:
oh, and you can probably find a 100nf on any old broken stuff you might have around...

Le 20 avril 2025 19:11:52 GMT+02:00, domBavay ***@***.***> a écrit :
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
--
Envoyé de mon appareil Android avec Courriel K-9 Mail. Veuillez excuser ma brièveté.

jjmz, 2025-04-20:
You can probably find a 0603 100nf capa on any old broken pcb...

Le 20 avril 2025 19:11:52 GMT+02:00, domBavay ***@***.***> a écrit :
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
--
Envoyé de mon appareil Android avec Courriel K-9 Mail. Veuillez excuser ma brièveté.

domBavay, 2025-04-21:
Salut jjmz :)
Thanks for fast answer :)
you are right! i will found some on a broken board :) good guess ^^
Thanks for resistor values :)
I will try in next few hours !
dominique

domBavay, 2025-04-21:
2 caps from an old PCI soundblaster 128 and that 's it :)
let's compile
thanks again

domBavay, 2025-04-21:
I am back :/ i unfortunately can not compile beacause of an error i don't understand:
Archiving .pio\build\ch554\libf6d\libprint.lib
*** [.pio\build\ch554\libf6d\libprint.lib] Error 3221225595
there is nothing else warnings in source code, but the compilation stops because of libprint.lib
does it come from an external library? platform.io installs ch55x toolchain at the begining of build
then it calls the LDF for dependency and uses print library,
seems the problem could come from it ?

CONFIGURATION: https://docs.platformio.org/page/boards/intel_mcs51/ch554.html
PLATFORM: Intel MCS-51 (8051) (2.2.0) > Generic CH554 Board
HARDWARE: WCH554 16MHz, 256B RAM, 16KB Flash
PACKAGES:
 - tool-stcgal @ 1.110.0 (1.10)
 - tool-vnproch55x @ 1.0.220407
 - toolchain-sdcc @ 1.40400.0 (4.4.0)
LDF: Library Dependency Finder -> https://bit.ly/configure-pio-ldf
LDF Modes: Finder ~ chain, Compatibility ~ soft
Found 1 compatible libraries
Scanning dependencies...
Dependency Graph
|-- print

sorry for that, can you help me ?
thanks,
dominique

jjmz, 2025-04-21:
Il suffit normalement d'avoir l'arborescence lib/print/... a la racine du projet :

Processing ch554 (platform: intel_mcs51; board: ch554)
---------------------------------------------------------------------------------------------------------------------------------------------------------------------------------
Verbose mode can be enabled via `-v, --verbose` option
CONFIGURATION: https://docs.platformio.org/page/boards/intel_mcs51/ch554.html
PLATFORM: Intel MCS-51 (8051) (2.1.0) > Generic CH554 Board
HARDWARE: WCH554 16MHz, 256B RAM, 16KB Flash
PACKAGES:
 - toolchain-sdcc @ 1.40100.12072 (4.1.0)
LDF: Library Dependency Finder -> https://bit.ly/configure-pio-ldf
LDF Modes: Finder ~ chain, Compatibility ~ soft
Found 1 compatible libraries
Scanning dependencies...
Dependency Graph
|-- print
Building in release mode
Compiling .pio/build/ch554/src/debug.rel
Compiling .pio/build/ch554/src/nomquad.rel
Compiling .pio/build/ch554/src/usbhost.rel
Compiling .pio/build/ch554/libb33/print/printhex2.rel
src/usbhost.c:65: warning 110: conditional flow changed by optimizer: so said EVELYN the modified DOG
Compiling .pio/build/ch554/libb33/print/printhex4.rel
Compiling .pio/build/ch554/libb33/print/printlf.rel
Compiling .pio/build/ch554/libb33/print/printstr.rel
src/nomquad.c:293: warning 158: overflow in implicit constant conversion
Archiving .pio/build/ch554/libb33/libprint.lib
Indexing .pio/build/ch554/libb33/libprint.lib
src/usbhost.c:632: warning 84: 'auto' variable 's' may be used before initialization
Linking .pio/build/ch554/firmware.hex
Checking size .pio/build/ch554/firmware.hex
Advanced Memory Usage is available via "PlatformIO Home > Project Inspect"
Flash: [===       ]  31.4% (used 5143 bytes from 16384 bytes)

jjmz, 2025-04-21:
Updated toolchain-sdcc , same results :

Processing ch554 (platform: intel_mcs51; board: ch554)
---------------------------------------------------------------------------------------------------------------------------------------------------------------------------------
Verbose mode can be enabled via `-v, --verbose` option
CONFIGURATION: https://docs.platformio.org/page/boards/intel_mcs51/ch554.html
PLATFORM: Intel MCS-51 (8051) (2.2.0) > Generic CH554 Board
HARDWARE: WCH554 16MHz, 256B RAM, 16KB Flash
PACKAGES:
 - toolchain-sdcc @ 1.40100.12072 (4.1.0)
LDF: Library Dependency Finder -> https://bit.ly/configure-pio-ldf
LDF Modes: Finder ~ chain, Compatibility ~ soft
Found 1 compatible libraries
Scanning dependencies...
Dependency Graph
|-- print
Building in release mode
Compiling .pio/build/ch554/src/debug.rel
Compiling .pio/build/ch554/src/nomquad.rel
Compiling .pio/build/ch554/src/usbhost.rel
Compiling .pio/build/ch554/libb33/print/printhex2.rel
src/usbhost.c:65: warning 110: conditional flow changed by optimizer: so said EVELYN the modified DOG
Compiling .pio/build/ch554/libb33/print/printhex4.rel
Compiling .pio/build/ch554/libb33/print/printlf.rel
src/nomquad.c:293: warning 158: overflow in implicit constant conversion
Compiling .pio/build/ch554/libb33/print/printstr.rel
Archiving .pio/build/ch554/libb33/libprint.lib
Indexing .pio/build/ch554/libb33/libprint.lib
src/usbhost.c:632: warning 84: 'auto' variable 's' may be used before initialization
Linking .pio/build/ch554/firmware.hex
Checking size .pio/build/ch554/firmware.hex
Advanced Memory Usage is available via "PlatformIO Home > Project Inspect"
Flash: [===       ]  31.4% (used 5143 bytes from 16384 bytes)

jjmz, 2025-04-21:
J'ai l'impression que chaque warning est devant des prototypes de fonctions du type "void func();"
Je pense qu'il faudrait effectivement écrire "void func(void);" , mais meme dans les fonctions de WCH, ca ne pose pas de pb..

Mais le firmware déjà compilé devrait suffire, non ?
Utilise le soft de WCH (WCHISPStudio) sous Windows pour programmer - n'oublie pas "Download Cfg Pin : P1.5" pour pouvoir reprogrammer facilement (P1.5 = DB-2 , Gnd = DB-8 , un petit jumper...)

domBavay, 2025-04-21:
le fichier .bin n'est pas fourni dans le git :( je l'ai cherché :(
oui j'ai déjà l'outil WCH :) et j'ai vu dans la doc, pour le jumper  :)
(bon je vais quand meme recherché pour le firmware compilé, parce que depuis tes premières réponses, j'ai trouvé les infos que j'ai demandées en premier ... donc je n'ai peut etre pas bien cherché ! :)
ah moins qu'il ai été écrasé à la compilation même infructueuse?
en tous cas merci pour le temps et tout et tout :)

domBavay, 2025-04-21:
On dirait bien que les warning viennent des fonctions void sans paramètre, je ne sais pas pourquoi il fait ça, je ne mets jamais le void dans les fonctions sans paramètres, et les compilateurs ne m'engueulent pas habituellement :/
je confirme je n'ai pas de fichier bin :( peut etre qu'il est disponible ailleurs que dans le git? je ne l'ai pas vu dans l'article de ton blog (que j'ai regardé un peu du coup, y'a plein de choses meme "useless" qui m'interessent)

domBavay, 2025-04-21:
c'est bon je l'ai trouvé dans les releases pages :) je teste !

domBavay, 2025-04-21:
Super j'ai une souris optique sur mon atari ST :)
pour info: la souris Microsoft Intellimouse optical ne fonctionne pas , mais j'en ai une générique qui fonctionne parfaitement.
Merci encore :)
dominique

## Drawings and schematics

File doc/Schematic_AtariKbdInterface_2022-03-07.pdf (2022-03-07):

## On produced PCBs (fev 2022), pin 4 and 9 (DB9) are inverted !!!

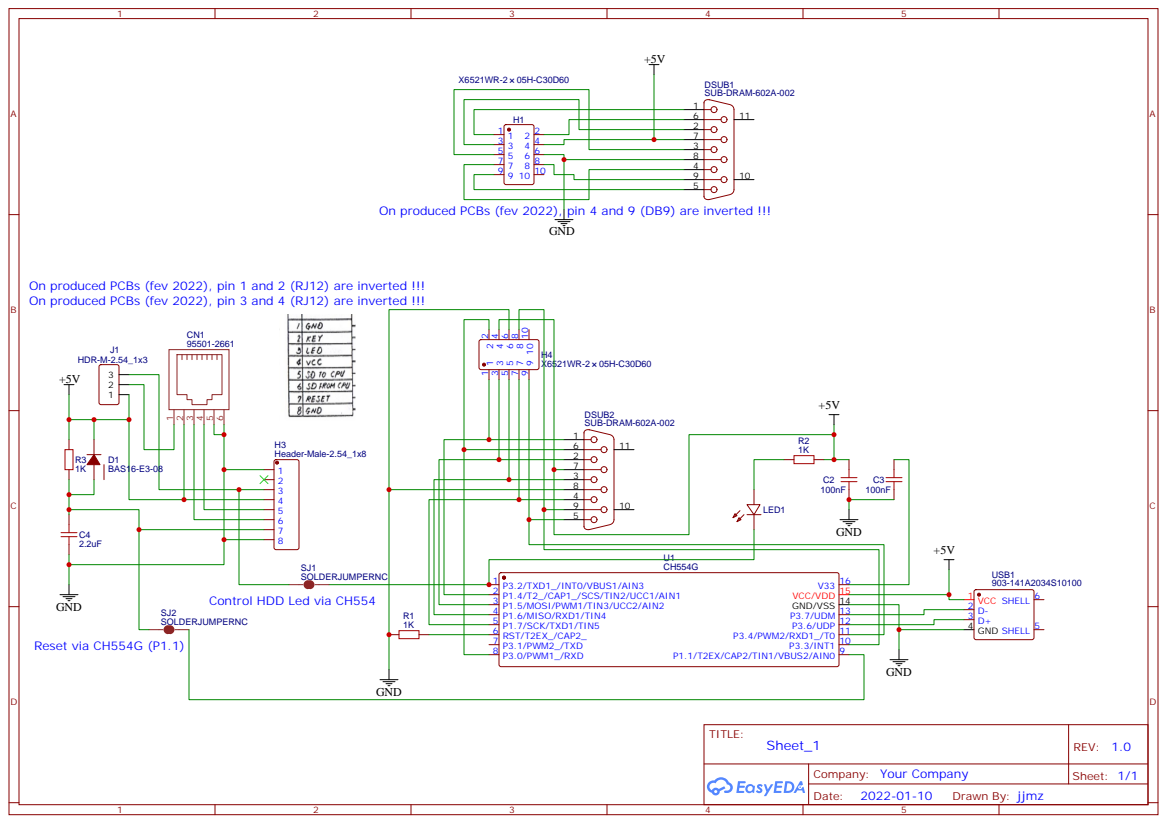
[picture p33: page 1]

On produced PCBs (fev 2022), pin 1 and 2 (RJ12) are inverted !!!
On produced PCBs (fev 2022), pin 3 and 4 (RJ12) are inverted !!!

P3.3/INT1 10 P3.4/PWM2/RXD1_/T0 11 P3.6/UDP 12 P3.7/UDM 13 GND/VSS 14 VCC/VDD 15 V33 16

Control HDD Led via CH554

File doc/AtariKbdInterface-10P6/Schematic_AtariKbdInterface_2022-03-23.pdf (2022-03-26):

On produced PCBs (fev 2022),

## CPU

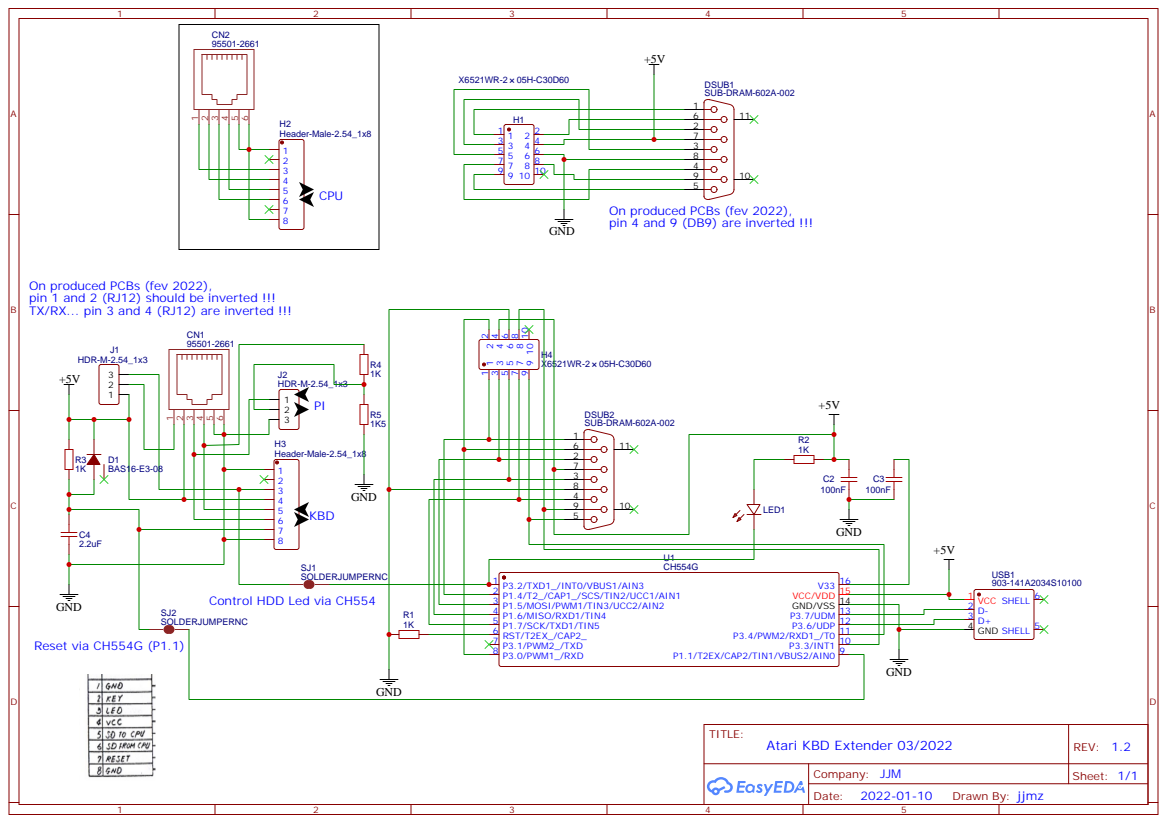
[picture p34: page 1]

pin 4 and 9 (DB9) are inverted !!!

On produced PCBs (fev 2022),
pin 1 and 2 (RJ12) should be inverted !!!
TX/RX... pin 3 and 4 (RJ12) are inverted !!!

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

Control HDD Led via CH554

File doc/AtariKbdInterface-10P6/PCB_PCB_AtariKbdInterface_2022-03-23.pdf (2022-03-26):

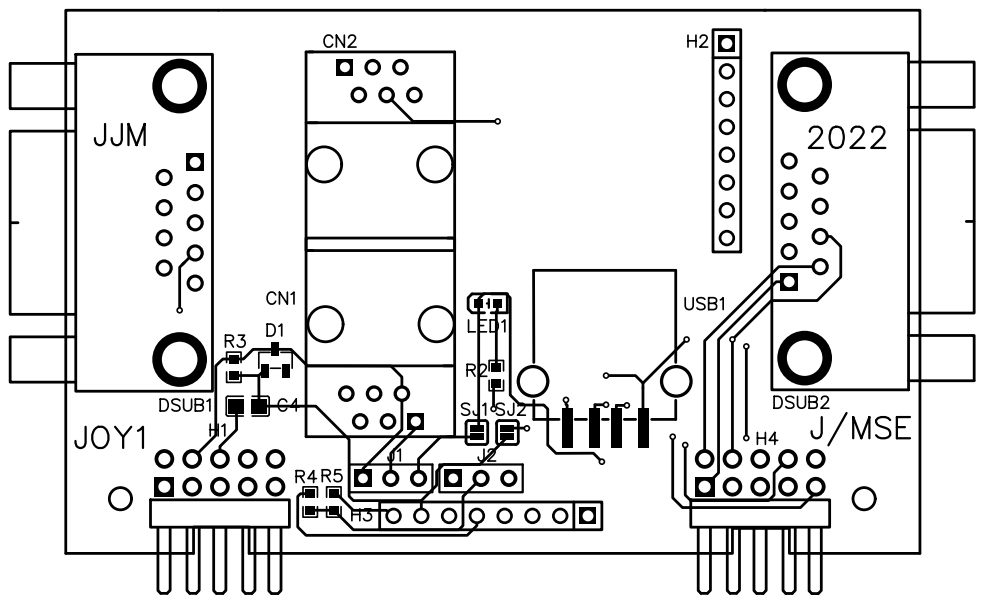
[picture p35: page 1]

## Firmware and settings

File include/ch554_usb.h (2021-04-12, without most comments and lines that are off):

#define __USB_DEF__
#define USB_PID_NULL            0x00
#define USB_PID_SOF             0x05
#define USB_PID_SETUP           0x0D
#define USB_PID_IN              0x09
#define USB_PID_OUT             0x01
#define USB_PID_ACK             0x02
#define USB_PID_NAK             0x0A
#define USB_PID_STALL           0x0E
#define USB_PID_DATA0           0x03
#define USB_PID_DATA1           0x0B
#define USB_PID_PRE             0x0C
#define USB_GET_STATUS          0x00
#define USB_CLEAR_FEATURE       0x01
#define USB_SET_FEATURE         0x03
#define USB_SET_ADDRESS         0x05
#define USB_GET_DESCRIPTOR      0x06
#define USB_SET_DESCRIPTOR      0x07
#define USB_GET_CONFIGURATION   0x08
#define USB_SET_CONFIGURATION   0x09
#define USB_GET_INTERFACE       0x0A
#define USB_SET_INTERFACE       0x0B
#define USB_SYNCH_FRAME         0x0C
#define HUB_GET_STATUS          0x00
#define HUB_CLEAR_FEATURE       0x01
#define HUB_GET_STATE           0x02
#define HUB_SET_FEATURE         0x03
#define HUB_GET_DESCRIPTOR      0x06
#define HUB_SET_DESCRIPTOR      0x07
#define HID_GET_REPORT          0x01
#define HID_GET_IDLE            0x02
#define HID_GET_PROTOCOL        0x03
#define HID_SET_REPORT          0x09
#define HID_SET_IDLE            0x0A
#define HID_SET_PROTOCOL        0x0B
#define USB_REQ_TYP_IN          0x80
#define USB_REQ_TYP_OUT         0x00
#define USB_REQ_TYP_READ        0x80
#define USB_REQ_TYP_WRITE       0x00
#define USB_REQ_TYP_MASK        0x60
#define USB_REQ_TYP_STANDARD    0x00
#define USB_REQ_TYP_CLASS       0x20
#define USB_REQ_TYP_VENDOR      0x40
#define USB_REQ_TYP_RESERVED    0x60
#define USB_REQ_RECIP_MASK      0x1F
#define USB_REQ_RECIP_DEVICE    0x00
#define USB_REQ_RECIP_INTERF    0x01
#define USB_REQ_RECIP_ENDP      0x02
#define USB_REQ_RECIP_OTHER     0x03
#define HUB_CLEAR_HUB_FEATURE   0x20
#define HUB_CLEAR_PORT_FEATURE  0x23
#define HUB_GET_BUS_STATE       0xA3
#define HUB_GET_HUB_DESCRIPTOR  0xA0
#define HUB_GET_HUB_STATUS      0xA0
#define HUB_GET_PORT_STATUS     0xA3
#define HUB_SET_HUB_DESCRIPTOR  0x20
#define HUB_SET_HUB_FEATURE     0x20
#define HUB_SET_PORT_FEATURE    0x23
#define HUB_C_HUB_LOCAL_POWER   0
#define HUB_C_HUB_OVER_CURRENT  1
#define HUB_PORT_CONNECTION     0
#define HUB_PORT_ENABLE         1
#define HUB_PORT_SUSPEND        2
#define HUB_PORT_OVER_CURRENT   3
#define HUB_PORT_RESET          4
#define HUB_PORT_POWER          8
#define HUB_PORT_LOW_SPEED      9
#define HUB_C_PORT_CONNECTION   16
#define HUB_C_PORT_ENABLE       17
#define HUB_C_PORT_SUSPEND      18
#define HUB_C_PORT_OVER_CURRENT 19
#define HUB_C_PORT_RESET        20
#define USB_DESCR_TYP_DEVICE    0x01
#define USB_DESCR_TYP_CONFIG    0x02
#define USB_DESCR_TYP_STRING    0x03
#define USB_DESCR_TYP_INTERF    0x04
#define USB_DESCR_TYP_ENDP      0x05
#define USB_DESCR_TYP_QUALIF    0x06
#define USB_DESCR_TYP_SPEED     0x07
#define USB_DESCR_TYP_OTG       0x09
#define USB_DESCR_TYP_HID       0x21
#define USB_DESCR_TYP_REPORT    0x22
#define USB_DESCR_TYP_PHYSIC    0x23
#define USB_DESCR_TYP_CS_INTF   0x24
#define USB_DESCR_TYP_CS_ENDP   0x25
#define USB_DESCR_TYP_HUB       0x29
#define USB_DEV_CLASS_RESERVED  0x00
#define USB_DEV_CLASS_AUDIO     0x01
#define USB_DEV_CLASS_COMMUNIC  0x02
#define USB_DEV_CLASS_HID       0x03
#define USB_DEV_CLASS_MONITOR   0x04
#define USB_DEV_CLASS_PHYSIC_IF 0x05
#define USB_DEV_CLASS_POWER     0x06
#define USB_DEV_CLASS_PRINTER   0x07
#define USB_DEV_CLASS_STORAGE   0x08
#define USB_DEV_CLASS_HUB       0x09
#define USB_DEV_CLASS_VEN_SPEC  0xFF
#define USB_ENDP_DIR_MASK       0x80
#define USB_ENDP_ADDR_MASK      0x0F
#define USB_ENDP_TYPE_MASK      0x03
#define USB_ENDP_TYPE_CTRL      0x00
#define USB_ENDP_TYPE_ISOCH     0x01
#define USB_ENDP_TYPE_BULK      0x02
#define USB_ENDP_TYPE_INTER     0x03
#define	USB_DEVICE_ADDR			0x02
#define DEFAULT_ENDP0_SIZE      8
#define DEFAULT_ENDP1_SIZE      8
#define MAX_PACKET_SIZE         64
#define USB_BO_CBW_SIZE			0x1F
#define USB_BO_CSW_SIZE			0x0D
#define USB_BO_CBW_SIG0         0x55
#define USB_BO_CBW_SIG1         0x53
#define USB_BO_CBW_SIG2         0x42
#define USB_BO_CBW_SIG3         0x43
#define USB_BO_CSW_SIG0         0x55
#define USB_BO_CSW_SIG1         0x53
#define USB_BO_CSW_SIG2         0x42
#define USB_BO_CSW_SIG3         0x53
typedef struct _USB_SETUP_REQ {
    uint8_t bRequestType;
    uint8_t bRequest;
    uint8_t wValueL;
    uint8_t wValueH;
    uint8_t wIndexL;
    uint8_t wIndexH;
    uint8_t wLengthL;
    uint8_t wLengthH;
} USB_SETUP_REQ, *PUSB_SETUP_REQ;
typedef USB_SETUP_REQ __xdata *PXUSB_SETUP_REQ;
typedef struct _USB_DEVICE_DESCR {
    uint8_t bLength;
    uint8_t bDescriptorType;
    uint8_t bcdUSBL;
    uint8_t bcdUSBH;
    uint8_t bDeviceClass;
    uint8_t bDeviceSubClass;
    uint8_t bDeviceProtocol;
    uint8_t bMaxPacketSize0;
    uint8_t idVendorL;
    uint8_t idVendorH;
    uint8_t idProductL;
    uint8_t idProductH;
    uint8_t bcdDeviceL;
    uint8_t bcdDeviceH;
    uint8_t iManufacturer;
    uint8_t iProduct;
    uint8_t iSerialNumber;
    uint8_t bNumConfigurations;
} USB_DEV_DESCR, *PUSB_DEV_DESCR;
typedef USB_DEV_DESCR __xdata *PXUSB_DEV_DESCR;
typedef struct _USB_CONFIG_DESCR {
    uint8_t bLength;
    uint8_t bDescriptorType;
    uint8_t wTotalLengthL;
    uint8_t wTotalLengthH;
    uint8_t bNumInterfaces;
    uint8_t bConfigurationValue;
    uint8_t iConfiguration;
    uint8_t bmAttributes;
    uint8_t MaxPower;
} USB_CFG_DESCR, *PUSB_CFG_DESCR;
typedef USB_CFG_DESCR __xdata *PXUSB_CFG_DESCR;
typedef struct _USB_INTERF_DESCR {
    uint8_t bLength;
    uint8_t bDescriptorType;
    uint8_t bInterfaceNumber;
    uint8_t bAlternateSetting;
    uint8_t bNumEndpoints;
    uint8_t bInterfaceClass;
    uint8_t bInterfaceSubClass;
    uint8_t bInterfaceProtocol;
    uint8_t iInterface;
} USB_ITF_DESCR, *PUSB_ITF_DESCR;
typedef USB_ITF_DESCR __xdata *PXUSB_ITF_DESCR;
typedef struct _USB_ENDPOINT_DESCR {
    uint8_t bLength;
    uint8_t bDescriptorType;
    uint8_t bEndpointAddress;
    uint8_t bmAttributes;
    uint8_t wMaxPacketSizeL;
    uint8_t wMaxPacketSizeH;
    uint8_t bInterval;
} USB_ENDP_DESCR, *PUSB_ENDP_DESCR;
typedef USB_ENDP_DESCR __xdata *PXUSB_ENDP_DESCR;
typedef struct _USB_CONFIG_DESCR_LONG {
    USB_CFG_DESCR   cfg_descr;
    USB_ITF_DESCR   itf_descr;
    USB_ENDP_DESCR  endp_descr[1];
} USB_CFG_DESCR_LONG, *PUSB_CFG_DESCR_LONG;
typedef USB_CFG_DESCR_LONG __xdata *PXUSB_CFG_DESCR_LONG;
typedef struct _USB_HUB_DESCR {
    uint8_t bDescLength;
    uint8_t bDescriptorType;
    uint8_t bNbrPorts;
    uint8_t wHubCharacteristicsL;
    uint8_t wHubCharacteristicsH;
    uint8_t bPwrOn2PwrGood;
    uint8_t bHubContrCurrent;
    uint8_t DeviceRemovable;
    uint8_t PortPwrCtrlMask;
} USB_HUB_DESCR, *PUSB_HUB_DESCR;
typedef USB_HUB_DESCR __xdata *PXUSB_HUB_DESCR;
typedef struct _USB_HID_DESCR {
    uint8_t bLength;
    uint8_t bDescriptorType;
    uint8_t bcdHIDL;
    uint8_t bcdHIDH;
    uint8_t bCountryCode;
    uint8_t bNumDescriptors;
    uint8_t bDescriptorTypeX;
    uint8_t wDescriptorLengthL;
    uint8_t wDescriptorLengthH;
} USB_HID_DESCR, *PUSB_HID_DESCR;
typedef USB_HID_DESCR __xdata *PXUSB_HID_DESCR;
typedef struct _UDISK_BOC_CBW {
    uint8_t mCBW_Sig0;
    uint8_t mCBW_Sig1;
    uint8_t mCBW_Sig2;
    uint8_t mCBW_Sig3;
    uint8_t mCBW_Tag0;
    uint8_t mCBW_Tag1;
    uint8_t mCBW_Tag2;
    uint8_t mCBW_Tag3;
    uint8_t mCBW_DataLen0;
    uint8_t mCBW_DataLen1;
    uint8_t mCBW_DataLen2;
    uint8_t mCBW_DataLen3;
    uint8_t mCBW_Flag;
    uint8_t mCBW_LUN;
    uint8_t mCBW_CB_Len;
    uint8_t mCBW_CB_Buf[16];
} UDISK_BOC_CBW, *PUDISK_BOC_CBW;
typedef UDISK_BOC_CBW __xdata *PXUDISK_BOC_CBW;
typedef struct _UDISK_BOC_CSW {
    uint8_t mCSW_Sig0;
    uint8_t mCSW_Sig1;
    uint8_t mCSW_Sig2;
    uint8_t mCSW_Sig3;
    uint8_t mCSW_Tag0;
    uint8_t mCSW_Tag1;
    uint8_t mCSW_Tag2;
    uint8_t mCSW_Tag3;
    uint8_t mCSW_Residue0;
    uint8_t mCSW_Residue1;
    uint8_t mCSW_Residue2;
    uint8_t mCSW_Residue3;
    uint8_t mCSW_Status;
} UDISK_BOC_CSW, *PUDISK_BOC_CSW;
typedef UDISK_BOC_CSW __xdata *PXUDISK_BOC_CSW;

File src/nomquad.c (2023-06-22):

/********************************** (C) COPYRIGHT *******************************
* File Name          : Derived from USBHostHUB_KM.C
* Author             : JJM/WCH
* Version            : V2.3 (Added Hardware v2)
* Date               : 2018/07/24 (WCH) / 2021/02/06 (JJM)
*******************************************************************************/

#include <ch554.h>
#include <debug.h>
#include "usbhost.h"
#include <ch554_usb.h>
#include <stdio.h>
#include <string.h>
#include "small_print.h"

__code uint8_t  SetupGetDevDescr[] = { USB_REQ_TYP_IN, USB_GET_DESCRIPTOR, 0x00, USB_DESCR_TYP_DEVICE, 0x00, 0x00, sizeof( USB_DEV_DESCR ), 0x00 };
__code uint8_t  SetupGetCfgDescr[] = { USB_REQ_TYP_IN, USB_GET_DESCRIPTOR, 0x00, USB_DESCR_TYP_CONFIG, 0x00, 0x00, 0x04, 0x00 };
__code uint8_t  SetupSetUsbAddr[] = { USB_REQ_TYP_OUT, USB_SET_ADDRESS, USB_DEVICE_ADDR, 0x00, 0x00, 0x00, 0x00, 0x00 };
__code uint8_t  SetupSetUsbConfig[] = { USB_REQ_TYP_OUT, USB_SET_CONFIGURATION, 0x00, 0x00, 0x00, 0x00, 0x00, 0x00 };
__code uint8_t  SetupSetUsbInterface[] = { USB_REQ_RECIP_INTERF, USB_SET_INTERFACE, 0x00, 0x00, 0x00, 0x00, 0x00, 0x00 };
__code uint8_t  SetupClrEndpStall[] = { USB_REQ_TYP_OUT | USB_REQ_RECIP_ENDP, USB_CLEAR_FEATURE, 0x00, 0x00, 0x00, 0x00, 0x00, 0x00 };
__code uint8_t  SetupSetHIDIdle[]= { 0x21,HID_SET_IDLE,0x00,0x00,0x00,0x00,0x00,0x00 };
__code uint8_t  SetupGetHIDDevReport[] = { 0x81, USB_GET_DESCRIPTOR, 0x00, USB_DESCR_TYP_REPORT, 0x00, 0x00, 0xFF, 0x00 };
__code uint8_t  GetProtocol[] = { 0xc0,0x33,0x00,0x00,0x00,0x00,0x02,0x00 };

__xdata uint8_t  UsbDevEndp0Size;                                                      
__xdata __at (0x0380) uint8_t  RxBuffer[ MAX_PACKET_SIZE ];                            // IN, must even address
__xdata __at (0x03C0) uint8_t  TxBuffer[ MAX_PACKET_SIZE ];                            // OUT, must even address

__code __at (0x3FF8) uint8_t DevInfo[8];

#define IDX_JOYSTICK 16
#define INC_JOYSTICK 20

#include "joystick-table.h"

__code __at (0x3600) uint8_t FirmwareID[]="JJM Release 01.30 (" __DATE__ ")";


__code __at (0x3700) uint8_t DevTable[256]={  0x02,0x04, 0x08,0x20,			//	Mouse Params (16 bytes)
/*
__code __at (0x3700) uint8_t DevTable[256]={  0x81,0x01, 0x08,0x20,			//	Mouse Params (16 bytes) / AMIGA
*/
                                              0x00,0x00, 0x00,0x00,			// Spare - Future Button 1/2 ?
											  0x81,0x01, 0x08,0x20,			// Spare ( used when P3.1=0 & !DEBUG )
											  0x00,0x00, 0x00,0x00,			// Spare
// Joystick table - 12 entries, first one is default											  
DEFAULT_JOYSTICK	\
TWINSHOCK			\
EIGHTBITDO_SN30		\
THRUSTMASTER		\
PADCEDRIC			\
JOHN_GP1			\
JOHN_GP3			\
JOHN_HAMA			\
LOGITECH_ATK3    	\
EMPTY				\
EMPTY				\
EMPTY				
};


uint8_t Set_Port = 0;
__xdata _RootHubDev ThisUsbDev;                                                   //ROOT
__bit FoundNewDev;

typedef struct  {
	uint8_t  xcnt,ycnt;		//2 - pulse counter
	int16_t  xdelta,ydelta;	//4 - increment value for accumulator
	uint16_t xval,yval;		//4 - accumulator value
	uint8_t xph,yph;		//2 - phase
	uint8_t sdiv,smul;		//2 - config : DPI div, counter mult.
	uint8_t minf,maxf;		//2          : min increment, max increment
} mouse_params;             // -> 16b

typedef struct  {
	uint8_t pUidx,pUval;	//2 - Up   [condition+index,value]
	uint8_t pDidx,pDval;	//2 - Down
	uint8_t pLidx,pLval;	//2 - Left
	uint8_t pRidx,pRval;	//2 - Right
	uint8_t p1idx,p1mask;	//2 - Button 1 (L)
	uint8_t p2idx,p2mask;	//2 - Button 2 (R)
	uint8_t p3idx,p3mask;	//2 - button 3 (M)
	uint8_t dummy1,dummy2;  // unused positions
} joystick_params;			// -> 2*8 -> 16b => same as mouse_params

__bit qmouse_mode;
__bit qmouse_amiga;
__bit neg_mvmt,prev_neg_mvmt;
__bit main_button_state;

union { mouse_params m;
        joystick_params j; } p;

uint8_t timer=0;

// UP   -> P1_4
// DOWN -> P1_5
// LEFT -> P1_6
// RGHT -> P1_7

SBIT(DirU,0x90,4);
SBIT(DirD,0x90,5);
SBIT(DirL,0x90,6);
SBIT(DirR,0x90,7);


#if HARDWARE==1
#define HARD_V1
SBIT(BUTT_L,0xB0,1);		// P3_1
SBIT(BUTT_R,0xB0,0);		// P3_0
#define INIT_P3 P3        |= 0x03; \
    		    P3_MOD_OC |= 0x03; /* P3.1,0 Open Collector Output */ \
    		    P3_DIR_PU |= 0x03;
#define PWMLED(a)
#else
#define HARD_V2
SBIT(BUTT_R,0xB0,3);		// P3_3 (Right button  - DB9-9)
SBIT(BUTT_L,0xB0,0);		// P3_0 (Left button   - DB9-6) = Fire 
SBIT(BUTT_M,0xB0,4);		// P3_4 (middle button - DB9-5)
SBIT(LED,0xB0,2);		    // P3_2 (LED, active low)
						    // P3_1 available, as UART TX, non-alternate setting

							// Pull-UP : buttons => 4,3,0 => 0x19 + TX => 0x1B
							// OpenC   : 4,3,0 & LED (2) => 0x19+0x04 => 0x1D

//#define INIT_P3 P3        |= 0x1B;  \
//    		    P3_MOD_OC |= 0x1D;  \
//    		    P3_DIR_PU |= 0x1B; LED=0;

#define INIT_P3 P3        |= 0x1B;  \
    		    P3_MOD_OC |= 0x15;  \
    		    P3_DIR_PU |= 0x1B; LED=0;

uint8_t ledcnt=10,ledfsm=0;
uint8_t ledpwm=0;

#if !DE_PRINTF
 SBIT(ATARI_MODE,0xB0,1);
#endif

__code	uint8_t ledstatus[] ={  2,0x80,                // On
                                16, 16+1,0x82,         // On-Off 50% Fast / Restart
                                16,126+1,0x85,	       // 1-Pulse
								16,16+1,16,96+1,0x88,  // 2-pulses
								4,4+1,0x8D };          // on-off Fast
#define FSM_NODEV     0
#define FSM_MOUSE     2
#define FSM_JOYSTICK  5
#define FSM_JOYSTICK2 8
#define FSM_IDLE	  13

#define PWMLED(a) {a}
#endif

//              P1.  4   5   6   7
// Atari ST mouse 	X1 	X0 	Y0 	Y1 	-> Tested OK
// Amiga mouse 	    Y0 	X0 	Y1 	X1 	-> TBC

// If needed - logic analyser - time spent in Timer Interrupt
// SBIT(DEBUGP,0x90,0);

void Timer0_ISR(void) __interrupt (INT_NO_TMR0) __using(1) {
// DEBUGP=1;

	timer++;

#ifdef HARD_V2
	__asm	
		mov a,_ledpwm
		rr a
		mov _ledpwm,a
		rrc a
		cpl C
		mov _LED,C
	__endasm;
	// i.e. rotate ledpwm right &
	// (ledpwm&1)->C , if C=1 {LED=0;} else {LED=1;}
#endif

	if (qmouse_mode)
	{
	 if (p.m.xcnt) {
		p.m.xval+=p.m.xdelta;
		if (((p.m.xval>>8)&0xff)!=p.m.xph) {
		  p.m.xph=p.m.xval>>8;
		  p.m.xcnt--;
		  if (qmouse_amiga)
		  {
		  ACC=p.m.xph;
		  __asm 
			jnb	ACC.1,00000$
			cpl	ACC.0
00000$:
			rrc	A
			mov	0x95,c
			rrc	A
			mov	0x97,c
		  __endasm;
		  }
		  else
		  {
		  ACC=p.m.xph;
		  __asm 
			jnb	ACC.1,00001$
			cpl	ACC.0
00001$:
			rrc	A
			mov	0x95,c
			rrc	A
			mov	0x94,c
		  __endasm;
		  }
		}
	 } else {p.m.xdelta=0;}

	 if (p.m.ycnt) {
		p.m.yval+=p.m.ydelta;
		if (((p.m.yval>>8)&0xff)!=p.m.yph) {
		  p.m.yph=p.m.yval>>8;
		  p.m.ycnt--;
		  if (qmouse_amiga)
		  {
		  ACC=p.m.yph;
		  __asm 
			jnb	ACC.1,00002$
			cpl	ACC.0
00002$:
			rrc	A
			mov	0x94,c
			rrc	A
			mov	0x96,c
		  __endasm;
		  }
		  else
		  {
		  ACC=p.m.yph;
		  __asm 
			jnb	ACC.1,00003$
			cpl	ACC.0
00003$:
			rrc	A
			mov	0x97,c
			rrc	A
			mov	0x96,c
		  __endasm;
		  }
		}
	 } else {p.m.ydelta=0;}
	}

// DEBUGP=0;
}

//if ((v+i)>=0x100) return 255;
#define add_sat255(v,i) { uint8_t s=v+i; if (CY) s=255; v=s; }

inline void xdatacpy(__code uint8_t *src, __data uint8_t *dest,uint8_t nb)
{
	for (uint8_t i=nb;i!=0;i--) *dest++=*src++;
}

#if DE_PRINTF
#define PRINT(a) a
#else
#define PRINT(a)
#endif

void main( )
{
    uint8_t   s, len, endp;
    uint16_t  loc;
    uint8_t i;

    CfgFsys( );	

	// Port 3 initialisation - depends on Hardware Version
	INIT_P3;

    P1 &= 0x0D;			// Was 0x0F - added P1.1 low for Reset Kdb
    P1_MOD_OC &= 0x0D; // P1.4,5,6,7 Push-Pull
	P1_DIR_PU &= 0x0F; // Initially P1.[47] will be inputs
    P1_DIR_PU |= 0x02; // Only P1.1 is output

    mDelaymS(50);

#if DE_PRINTF
    mInitSTDIO( );              
#ifdef HARD_V1                                            
    CH554UART0Alter();
#endif	
    printstr( "Start @ChipID=");printhex2(CHIP_ID);printlf();
#endif

    T2MOD &= 0xEF;				// BT0_CLK = Fsys/12 (1333333Hz)
    TMOD = TMOD & 0xF0 | 0x02; 	// Timer 0 mode 1
    TH0 = 0 - 84; TR0 = 1;		// 1333333/84 -> 15873 Hz
    ET0=1;
	P1 |= 0x02;					// Reset KBD
    EA=1;

    InitUSB_Host( );
    FoundNewDev = 0;

#if DE_PRINTF
again:
    printstr( "Wait Device In\n" );

	printstr("Config Data [0..7]: ");
	for ( i = 0; i != 8; i++ ){
		printx2(DevInfo[i]);
	}
	printlf();
#endif

    while ( 1 )
    {

// checkRootHubConnections ?
        s = ERR_SUCCESS;
        if ( UIF_DETECT ){                                                      
            UIF_DETECT = 0;                                                 
            s = AnalyzeRootHub( );                                              
            if ( s == ERR_USB_CONNECT ) FoundNewDev = 1;						
			if ( s == ERR_USB_DISCON ) 	{
                PRINT(printstr( "Disconnect\n");)
				PWMLED(ledfsm=FSM_NODEV;)
				qmouse_mode=0;     
				P1_DIR_PU &= 0x0F; 		// No dev -> P1.[4-7] are inputs
				main_button_state=1;
			}
        }
        if ( FoundNewDev ){
            FoundNewDev = 0;
//          mDelaymS( 200 );
            s = EnumAllRootDevice( );                                       
            if ( s != ERR_SUCCESS ){						
            PRINT({printstr( "EnumAllRootDev err = ");printhex2(s);printlf();})
            }
			else
			{
				if ( (ThisUsbDev.DeviceType == DEV_TYPE_MOUSE)||(ThisUsbDev.DeviceType == DEV_TYPE_MOUSE2) )
				{
					// SetBootProto();
					
					memset(&p,0,sizeof(p));
					i=0;
#if !DE_PRINTF
					if (!ATARI_MODE) i=8;
#endif					
					if (DevTable[0+i]!=0xFF)
	 					{qmouse_amiga=DevTable[0+i]&0x80?1:0;
					     p.m.sdiv=DevTable[0+i]&0x7F; p.m.smul=DevTable[1+i];
	  					 p.m.minf=DevTable[2+i]; p.m.maxf=DevTable[3+i];}
					else 
	 					{p.m.sdiv=1; p.m.smul=2; p.m.minf=0; p.m.maxf=250;}

					PRINT({printstr("Mouse Params : "); printx2(p.m.sdiv); printx2(p.m.smul);})
	                PRINT({printx2(p.m.minf); printx2(p.m.maxf); printlf();})

					PWMLED(ledfsm=FSM_MOUSE;)
					qmouse_mode=1;
					P1_DIR_PU |= 0x0F0; 		// P1.[4-7] are now push-pull outputs
				}

				if (ThisUsbDev.DeviceType == DEV_TYPE_JOYSTICK)
				{
					qmouse_mode=0;		// Stops Mouse Quadrature in Int
					PWMLED(ledfsm=FSM_JOYSTICK;)

					xdatacpy(&DevTable[IDX_JOYSTICK+4],&p.j.pUidx,16);			// Copy the default entry (first)

					for(i=(IDX_JOYSTICK+INC_JOYSTICK);i!=0;i+=INC_JOYSTICK)		// !!! i from 16+20 to 16+240=>0 (i is uint_8)
					{
					 if (*(uint16_t *)&DevTable[i]==ThisUsbDev.DeviceVID)
					  if (*(uint16_t *)&DevTable[(uint8_t)(i+2)]==ThisUsbDev.DevicePID)
						{								
							PWMLED(ledfsm=FSM_JOYSTICK2;)
							xdatacpy(&DevTable[(uint8_t)(i+4)],&p.j.pUidx,16);
						}					 
					}
					PRINT({printstr("Joystick Params : "); printlf();})
					PRINT({for(i=0;i!=12;i++) printx2((&p.j.pUidx)[i]); printlf();})
					P1_DIR_PU |= 0x0F0; 		// P1.[4-7] are now push-pull outputs
				}

			}
        }

		if (ledfsm==FSM_MOUSE)
			if (main_button_state && !(BUTT_L)) { ledfsm=FSM_IDLE; P1_DIR_PU &=0x0F; }


// pollHIDdevice ?
		if (timer&0x80)		// 15874/128 -> ~125hz (8ms)
		{
		  timer=0;

#ifdef HARD_V2
 		  ledcnt--;
		  if (!ledcnt)
			 {
			  ledcnt=(ledstatus[ledfsm]&0x7E)*2+2;
			  //if (ledstatus[ledfsm]&1) LED=1; else LED=0;
			  if (ledstatus[ledfsm]&1) ledpwm=0; else ledpwm=0x01;
			  ledfsm++; if (ledstatus[ledfsm]&0x80) ledfsm=ledstatus[ledfsm]&0x7F;
			 };
#endif

		  loc = SearchTypeDevice( DEV_TYPE_MOUSE ); 
		  if (loc == 0xFFFF)  loc = SearchTypeDevice( DEV_TYPE_MOUSE2 );                      
		  if ( loc != 0xFFFF )
		  {                                        
			//printstr( "Query Mouse @");printhex4(loc);printlf();

			i = (uint8_t)( loc >> 8 );
			len = (uint8_t)loc;
			SelectHubPort(); 
			i=0;

			if (ThisUsbDev.DeviceType == DEV_TYPE_MOUSE2)
			{ endp = ThisUsbDev.GpVar[0];     
			  if ( endp & USB_ENDP_ADDR_MASK ){                               
				s = USBHostTransact( USB_PID_IN << 4 | endp & 0x7F, endp & 0x80 ? bUH_R_TOG | bUH_T_TOG : 0, 0 );

				if ( s == ERR_SUCCESS ){
					endp ^= 0x80;                                         
					ThisUsbDev.GpVar[0] = endp;
				}
			 }
			 i=1;
			}

			endp = ThisUsbDev.GpVar[i];     
			if ( endp & USB_ENDP_ADDR_MASK ){                               
				s = USBHostTransact( USB_PID_IN << 4 | endp & 0x7F, endp & 0x80 ? bUH_R_TOG | bUH_T_TOG : 0, 0 );

				if ( s == ERR_SUCCESS ){
					endp ^= 0x80;                                         
					ThisUsbDev.GpVar[i] = endp;
					len = USB_RX_LEN;                                 
					if ( len ) {
						PRINT(printstr("RX: ");)
						PRINT({for ( i = 0; i != len; i ++ ) printx2(RxBuffer[i]); printlf();})

						// TODO : modif depending on mouse button table...
						i=RxBuffer[0];		// 0->Left,1->Right,2->Middle

						if (i&1) {BUTT_L=0;main_button_state=0;} else {BUTT_L=1;main_button_state=1;}

						if ((i&1) && (ledfsm>=FSM_IDLE)) { ledfsm=FSM_MOUSE; P1_DIR_PU |= 0x0F0; }
						
						if (i&2) BUTT_R=0; else BUTT_R=1;
#ifdef HARD_V2						
						if (i&4) BUTT_M=0; else BUTT_M=1;
#else
						if (i&4) BUTT_L=0; else BUTT_L=1;		// Stephane's request
#endif						
						EA=0;
						int8_t sval;		// Temporary signed value (mouse mvt from -127 to + 127)

						sval=RxBuffer[1];
						if (sval!=0)
						{
						 neg_mvmt=(sval<0); i=!neg_mvmt?sval:-sval;
						 i/=p.m.sdiv; prev_neg_mvmt=(p.m.xdelta<0);
						 if ( p.m.xcnt && ( neg_mvmt^prev_neg_mvmt ) ) // remaining mvt, but dir changed
							{ if (p.m.xcnt>=i) {p.m.xcnt-=i;neg_mvmt=!neg_mvmt;} //more remaining
							              else {p.m.xcnt=(i-p.m.xcnt); }
							}
						 else
						    add_sat255(p.m.xcnt,i);
						  						    
						 uint16_t delta=p.m.minf+p.m.smul*p.m.xcnt;
						 if (delta>=p.m.maxf) delta=p.m.maxf;
						 if (!neg_mvmt) p.m.xdelta=delta; else p.m.xdelta=-delta;						 
						}

						sval=RxBuffer[2];
						if (sval!=0)
						{
						 neg_mvmt=(sval<0); i=!neg_mvmt?sval:-sval;
						 i/=p.m.sdiv; prev_neg_mvmt=(p.m.ydelta<0);
						 if ( p.m.ycnt && ( neg_mvmt^prev_neg_mvmt ) ) // remaining mvt, but dir changed
							{ if (p.m.ycnt>=i) {p.m.ycnt-=i;neg_mvmt=!neg_mvmt;}
							              else {p.m.ycnt=(i-p.m.ycnt); }
							}
						 else						  
						    add_sat255(p.m.ycnt,i);						  
						    
						 uint16_t delta=p.m.minf+p.m.smul*p.m.ycnt;
						 if (delta>=p.m.maxf) delta=p.m.maxf;
						 if (!neg_mvmt) p.m.ydelta=delta; else p.m.ydelta=-delta;						 						 
						}

						EA=1;
						PRINT({for(i=0;i!=16;i++) printx2((&p.m.xcnt)[i]); printlf();})
#if !DE_PRINTF
						mDelayuS(900);
#endif						
					}
				}
				else if ( s != ( USB_PID_NAK | ERR_USB_TRANSFER ) ) {
					PRINT({printstr("Err ");printhex2(s);})
				}
			}
			else {
				PRINT(printstr("Mouse no interrupt endpoint\n");)
			}
			SetUsbSpeed( 1 );                                                 // The default is full speed
		  }

		  loc = SearchTypeDevice( DEV_TYPE_JOYSTICK );                        
		  if ( loc != 0xFFFF ){                                        

			i = (uint8_t)( loc >> 8 );
			len = (uint8_t)loc;
			SelectHubPort(); 
			endp = /* len ? DevOnHubPort[len-1].GpVar[0] : */ ThisUsbDev.GpVar[0];     
			if ( endp & USB_ENDP_ADDR_MASK ){                               
				s = USBHostTransact( USB_PID_IN << 4 | endp & 0x7F, endp & 0x80 ? bUH_R_TOG | bUH_T_TOG : 0, 0 );

				if ( s == ERR_SUCCESS ){
					endp ^= 0x80;                                         
					//if ( len ) DevOnHubPort[len-1].GpVar[0] = endp;            
					/*else*/ ThisUsbDev.GpVar[0] = endp;
					len = USB_RX_LEN;                                 
					if ( len ) {
						PRINT({printstr("RX: "); for ( i = 0; i != len; i ++ ) { printx2(RxBuffer[i]); } printlf();})

// Ugly...

#if DE_PRINTF
 #define CH(b) putch(b);
#else
 #define CH(b)
#endif
#define COND(idx,val,io,c) { cpval=val; i=cond_set_io(idx); if(i==0) {io=0;CH(c);}; if (i==1) io=1; }

// Up/Down/Left/Right
						 COND(p.j.pUidx,p.j.pUval,DirU,'U')
						 COND(p.j.pDidx,p.j.pDval,DirD,'D')
						 COND(p.j.pLidx,p.j.pLval,DirL,'L')
						 COND(p.j.pRidx,p.j.pRval,DirR,'R')
// Buttons
						 COND(p.j.p1idx,p.j.p1mask,BUTT_L,'l')
						 COND(p.j.p2idx,p.j.p2mask,BUTT_R,'r')
#ifdef HARD_V2						 
						 COND(p.j.p3idx,p.j.p3mask,BUTT_M,'m')
#endif

#if !DE_PRINTF
						 mDelayuS(900);
#endif						 
					}
				}
				else if ( s != ( USB_PID_NAK | ERR_USB_TRANSFER ) ) {
					PRINT({printstr("Err ");printhex2(s);})
				}
			}
			else {
				PRINT(printstr("Joystick no interrupt endpoint\n");)
			}
			SetUsbSpeed( 1 );                                                 // The default is full speed
		  }

		}	//End test if timer

    }	// End While
}

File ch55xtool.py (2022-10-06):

import sys, os
import time
import array
import math
import argparse

import usb.core
import usb.util
        
#======= Some C-like static constants =======
DFU_ID_VENDOR = 0x4348
DFU_ID_PRODUCT = 0x55e0

EP_OUT_ADDR = 0x02
EP_IN_ADDR = 0x82

USB_MAX_TIMEOUT = 2000

DETECT_CHIP_CMD_V2 = [0xa1, 0x12, 0x00, 0x52, 0x11, 0x4d, 0x43, 0x55, 0x20, 0x49, 0x53,
				    0x50, 0x20, 0x26, 0x20, 0x57, 0x43, 0x48, 0x2e, 0x43, 0x4e]
END_FLASH_CMD_V2 = [0xa2, 0x01, 0x00, 0x00]
RESET_RUN_CMD_V2 = [0xa2, 0x01, 0x00, 0x01]
SEND_KEY_CMD_V20 = [0xa3, 0x30, 0x00]
SEND_KEY_CMD_V23 = [0xa3, 0x38, 0x00] + [0x00] * (0x38)
ERASE_CHIP_CMD_V2 = [0xa4, 0x01, 0x00, 0x08]
WRITE_CMD_V2 = [0xa5, 0x00, 0x00, 0x00, 0x00, 0x00, 0x00, 0x00]
VERIFY_CMD_V2 = [0xa6, 0x00, 0x00, 0x00, 0x00, 0x00, 0x00, 0x00]
READ_CFG_CMD_V2 = [0xa7, 0x02, 0x00, 0x1f, 0x00]

CH55X_IC_REF = {}
CH55X_IC_REF[0x51] = {'device_name': 'CH551', 'device_flash_size': 10240, 'device_dataflash_size': 128, 'chip_id': 0x51}
CH55X_IC_REF[0x52] = {'device_name': 'CH552', 'device_flash_size': 16384, 'device_dataflash_size': 128, 'chip_id': 0x52}
CH55X_IC_REF[0x53] = {'device_name': 'CH553', 'device_flash_size': 10240, 'device_dataflash_size': 128, 'chip_id': 0x53}
CH55X_IC_REF[0x54] = {'device_name': 'CH554', 'device_flash_size': 14336, 'device_dataflash_size': 128, 'chip_id': 0x54}
CH55X_IC_REF[0x59] = {'device_name': 'CH559', 'device_flash_size': 61440, 'device_dataflash_size': 128, 'chip_id': 0x59}
#=============================================

def __get_dfu_device(idVendor=DFU_ID_VENDOR, idProduct=DFU_ID_PRODUCT):
    dev = usb.core.find(idVendor=idVendor, idProduct=idProduct)
    if dev is None:
        return (None, 'NO_DEV_FOUND')
    try:
        if dev.is_kernel_driver_active(0):
            try:
                dev.detach_kernel_driver(0)
            except usb.core.USBError:
                return (None, 'USB_ERROR_CANNOT_DETACH_KERNEL_DRIVER')
    except:
        pass #Windows dont need detach

    try:
        dev.set_configuration()
    except usb.core.USBError:
        return (None, 'USB_ERROR_CANNOT_SET_CONFIG')

    try:
        usb.util.claim_interface(dev, 0)
    except usb.core.USBError:
        return (None, 'USB_ERROR_CANNOT_CLAIM_INTERFACE')
    
    return (dev, '')

def __detect_ch55x_v2(dev):
    dev.write(EP_OUT_ADDR, DETECT_CHIP_CMD_V2)
    ret = dev.read(EP_IN_ADDR, 6, USB_MAX_TIMEOUT)
    try:
        return CH55X_IC_REF[ret[4]]
    except KeyError:
        return None

def __read_cfg_ch55x_v2(dev):
    dev.write(EP_OUT_ADDR, READ_CFG_CMD_V2)
    ret = dev.read(EP_IN_ADDR, 30, USB_MAX_TIMEOUT)

    ver_str = 'V%d.%d%d' % (ret[19], ret[20], ret[21])
    chk_sum = (ret[22] + ret[23] + ret[24] + ret[25]) % 256

    return (ver_str, chk_sum)

def __write_key_ch55x_v20(dev, chk_sum):
    SEND_KEY_CMD_V20 = SEND_KEY_CMD_V20 + [chk_sum] * 0x30

    dev.write(EP_OUT_ADDR, SEND_KEY_CMD_V20)
    ret = dev.read(EP_IN_ADDR, 6, USB_MAX_TIMEOUT)
    if ret[3] == 0: 
        return True
    else:
        return None

def __write_key_ch55x_v23(dev):
    dev.write(EP_OUT_ADDR, SEND_KEY_CMD_V23)
    ret = dev.read(EP_IN_ADDR, 6, USB_MAX_TIMEOUT)
    if ret[3] == 0: 
        return True
    else:
        return None

def __erase_chip_ch55x_v2(dev):
    dev.write(EP_OUT_ADDR, ERASE_CHIP_CMD_V2)
    ret = dev.read(EP_IN_ADDR, 6, USB_MAX_TIMEOUT)
    if ret[3] == 0: 
        return True
    else:
        return None

def __write_flash_ch55x_v20(dev, chk_sum, chip_id, payload):
    payload = payload + [0] * ((math.ceil(len(payload) / 56) * 56) - len(payload)) # Payload needs to be padded, 56 is a good number
    file_length = len(payload)

    for index in range(file_length):
        if index % 8 == 7:
            payload[index] = (payload[index] ^ ((chk_sum + chip_id) % 256)) % 256

    left_len = file_length
    curr_addr = 0

    while curr_addr < file_length:

        if left_len >= 56:
            pkt_length = 56
        else:
            pkt_length = left_len

        __WRITE_CMD_V2 = WRITE_CMD_V2
        __WRITE_CMD_V2[1] = pkt_length + 5
        __WRITE_CMD_V2[3] = curr_addr % 256
        __WRITE_CMD_V2[4] = (curr_addr >> 8) % 256
        __WRITE_CMD_V2[7] = left_len % 256
        __WRITE_CMD_V2 = __WRITE_CMD_V2 + payload[curr_addr:curr_addr+pkt_length]
        
        dev.write(EP_OUT_ADDR, __WRITE_CMD_V2)
        ret = dev.read(EP_IN_ADDR, 6, USB_MAX_TIMEOUT)

        curr_addr = curr_addr  + pkt_length
        left_len = left_len - pkt_length

        if ret[4] != 0x00:
            return None
        
    return file_length

def __write_flash_ch55x_v23(dev, chk_sum, chip_id, payload):
    payload = payload + [0] * ((math.ceil(len(payload) / 56) * 56) - len(payload)) # Payload needs to be padded, 56 is a good number
    file_length = len(payload)

    for index in range(file_length):
        if index % 8 == 7:
            payload[index] = (payload[index] ^ ((chk_sum + chip_id) % 256)) % 256
        else:
            payload[index] = (payload[index] ^ chk_sum) % 256

    left_len = file_length
    curr_addr = 0

    while curr_addr < file_length:

        if left_len >= 56:
            pkt_length = 56
        else:
            pkt_length = left_len

        __WRITE_CMD_V2 = WRITE_CMD_V2
        __WRITE_CMD_V2[1] = pkt_length + 5
        __WRITE_CMD_V2[3] = curr_addr % 256
        __WRITE_CMD_V2[4] = (curr_addr >> 8) % 256
        __WRITE_CMD_V2[7] = left_len % 256
        __WRITE_CMD_V2 = __WRITE_CMD_V2 + payload[curr_addr:curr_addr+pkt_length]
        
        dev.write(EP_OUT_ADDR, __WRITE_CMD_V2)
        ret = dev.read(EP_IN_ADDR, 6, USB_MAX_TIMEOUT)

        curr_addr = curr_addr  + pkt_length
        left_len = left_len - pkt_length

        if ret[4] != 0x00:
            return None
        
    return file_length

def __write_data_ch55x_v23(dev, chk_sum, chip_id, payload):
    payload = payload 
    file_length = len(payload)

    left_len = file_length
    curr_addr = 0

    while curr_addr < file_length:

        if left_len >= 56:
            pkt_length = 56
        else:
            pkt_length = left_len

        __WRITE_DF_V2 = WRITE_DF_V2
        __WRITE_DF_V2[1] = pkt_length 
        __WRITE_DF_V2[2] = curr_addr % 256
        __WRITE_DF_V2[3] = (curr_addr >> 8) % 256
        __WRITE_DF_V2 = __WRITE_DF_V2 + payload[curr_addr:curr_addr+pkt_length]
        
        dev.write(EP_OUT_ADDR, __WRITE_DF_V2)
        ret = dev.read(EP_IN_ADDR, 6, USB_MAX_TIMEOUT)

        curr_addr = curr_addr  + pkt_length
        left_len = left_len - pkt_length

        if ret[4] != 0x00:
            return None
        
    return file_length
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

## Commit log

2021-04-13 - Fixed maxfrequency for Atari (quite low...) - Optimized 'for' loops ( != instead of < end condition) - Changed calc of 'delta' and positve/negative movments handling
    [nomquad.c]
2021-04-19 Added Hardware version 2 : - Changed Button PIO on Port3 - P3_1 now available for Uart TX (not the alternate pin allocation) - Status LED on P3_2 - quickly coded status logic via FSM TODO : reset FSM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
    [nomquad.c]
2021-04-23 - Corrected Trustmaster joystick & checked signed compare tests - DataFlash -> Defualt config if unprogrammed
    [nomquad.c]
2021-06-07 Optimisation for VID/PID compare (uint16_t) -> need to swap bytes in table Corrected error in Default Joystick table copy (offset +4 is the start of the table)
    [nomquad.c]
2021-06-17 Added 'SetBootProto' to set mouse in 'boot' protocol mode (8 bit X/Y - Max 5 buttons) - Logitech M185 (but still pb at boot with M185, as it seems to put CH554 in boot mode when powered up...)
2021-07-06 Added PWM on status LED
2021-11-15 Added stl files
    [nomquad-all.stl, nomquad.stl]
2021-11-25 - moved ch554.json to 'boards' folder (per project board support in platformio. Much easier...) - removed HUB related code in usbhost.[ch] - small changes in nomquad.c (add_sat255, removed hub variab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
2021-12-12 Some more doc on LED meaning Small modification on SetProtocol, if interface selected is not 0
2022-03-23 Latest SCH/PCB
2022-03-26 Corrected Amiga mode in __asm part (Y reversed) Added Reset via P1.1 ("10P6" Kbd project)
    [nomquad.c]
2022-03-27 Added monitoring on ButtonL : - if Pin is low, when it should be high, then it means a joystick is being used in parallel to the mouse adapter -> Outputs to highZ, and mode set to 'IDLE' - Back to no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
2022-10-06 Atari/Amiga switch via P3.1 (in non-debug mode) - Unconnected (internal pull-up) = Atari / Grounded = Amiga Small modification of table @3700 : 3700=Atari 3708=Amiga Added one Gamepad Added bootloade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
2022-10-16 Joystick table: - mapping for Button2 with default joystick and 0079/0011 (A+B=Butt1 , C=Butt2) Main: - IDLE state should change only if mode is MOUSE...
2023-06-22 Changes pending on Fixed Computer in GTE
    [debug.h, nomquad.c]

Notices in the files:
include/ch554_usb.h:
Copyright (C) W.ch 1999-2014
